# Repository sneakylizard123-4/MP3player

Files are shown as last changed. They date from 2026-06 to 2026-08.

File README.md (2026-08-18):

# MP3 Player

A pocket-sized music player I designed and built from scratch. It plays audio off a microSD card, tunes into FM radio, and can record through a MEMS microphone — all on one 50×70mm PCB with an OLED screen, RGB LEDs, and seventeen physical buttons.

It's built around an STM32H743 running at 480MHz, and the audio comes out through a CS43131 DAC. The whole thing was designed in KiCad 10 and the firmware is C++ written with PlatformIO on ST's HAL.

## Why I built this

I wanted a music player that was actually *mine*. Phones sound great and all, but you can't change anything about them — the hardware is sealed up, there's no satisfying button to press, and the software only does what the manufacturer lets it do. I wanted real buttons, a screen, lights that react to the music, and firmware I could rewrite from scratch whenever I felt like it.

It also turned out to be the perfect excuse to practice the stuff I actually enjoy: PCB design, embedded firmware, and getting hardware interfaces to talk to each other.

I went with the STM32H743 because it has the RAM to buffer audio properly, enough peripherals for everything I wanted to add, and 480MHz of headroom so I never have to worry about it being slow.

## Pictures

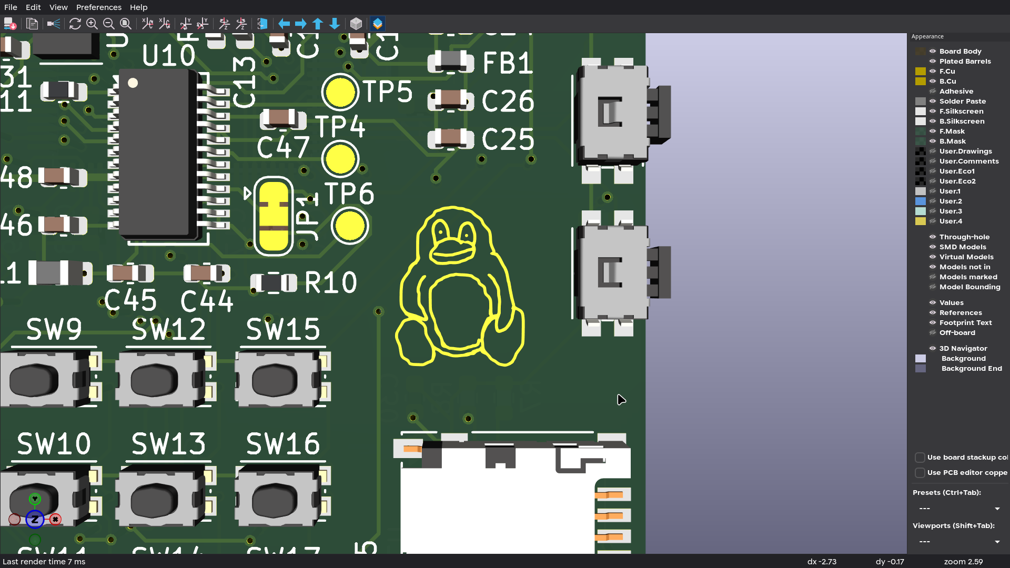
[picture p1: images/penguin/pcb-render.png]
3D render


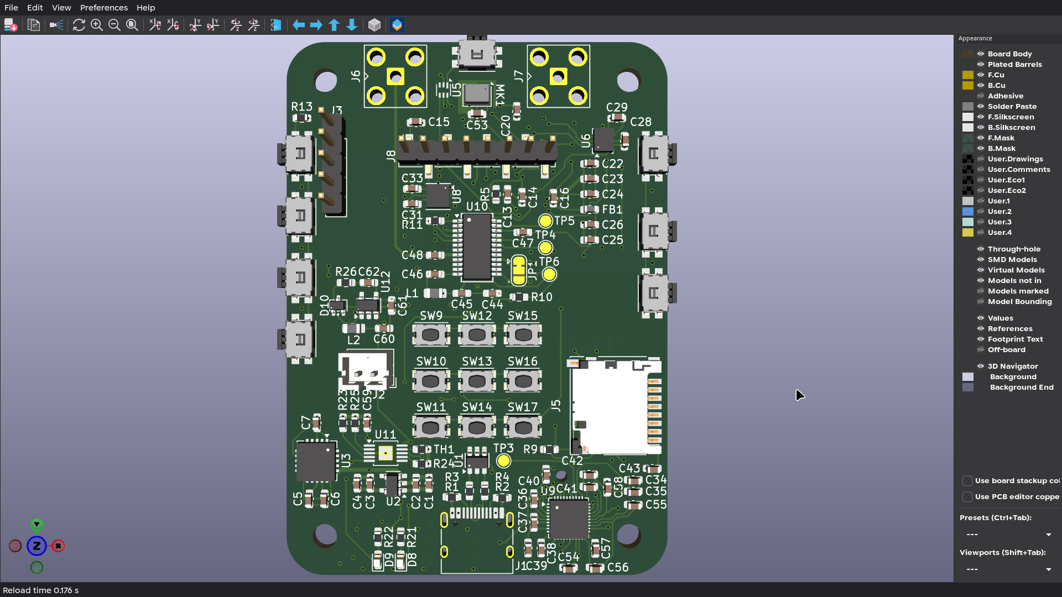
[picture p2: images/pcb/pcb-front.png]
PCB front
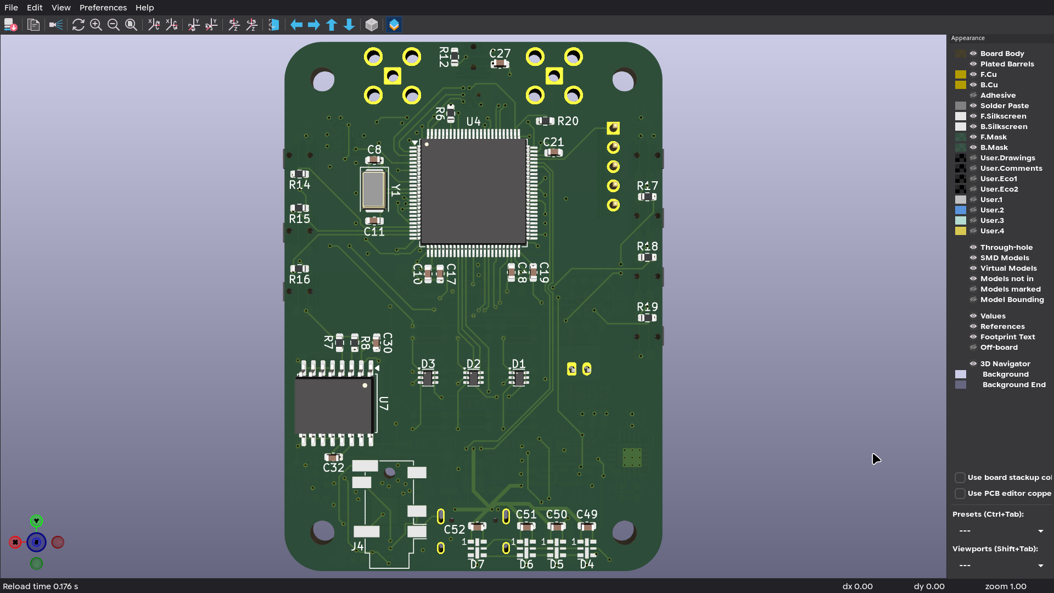
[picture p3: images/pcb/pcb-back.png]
PCB back
 | 

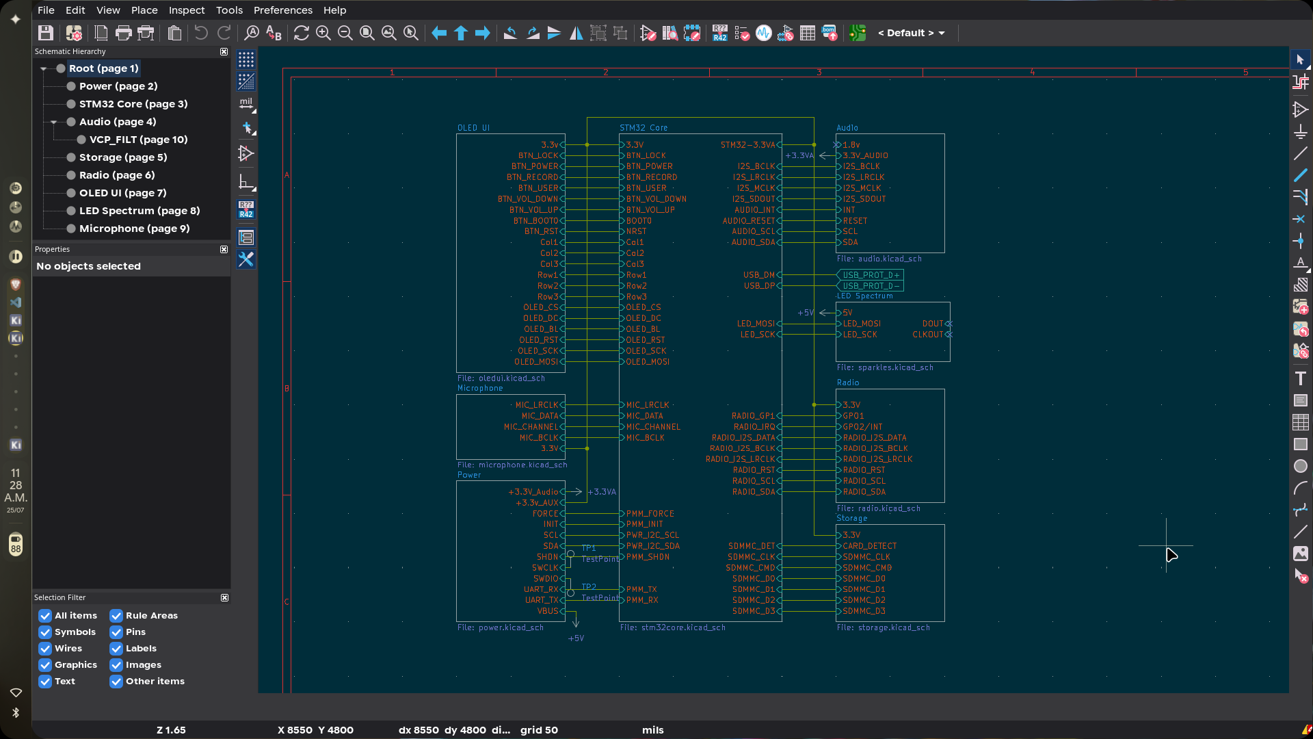
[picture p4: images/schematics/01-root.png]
Root schematic


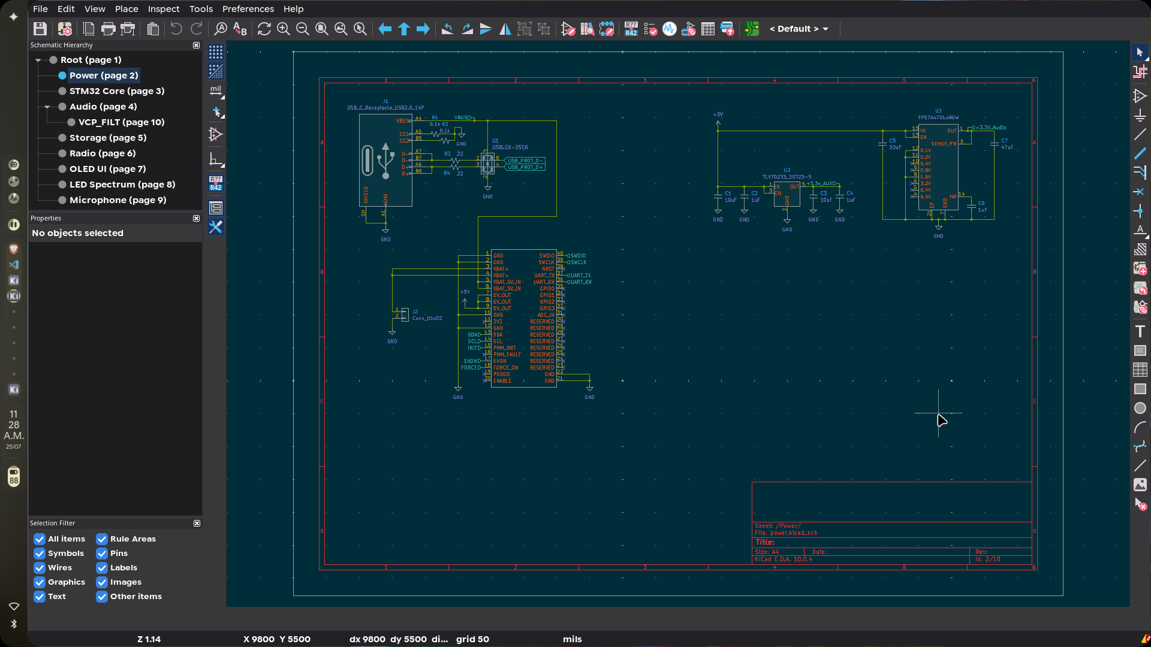
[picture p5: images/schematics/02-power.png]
Power schematic


## Features

**Audio**

* CS43131 high-res headphone DAC with a built-in amp
* Dedicated low-noise power rail just for the audio stuff
* 3.5mm headphone output
* Si4735 AM/FM radio receiver
* ICS-43434 I2S microphone for recording

**Storage & controls**

* microSD card over 4-bit SDMMC
* OLED display
* 17 buttons: a 3×3 matrix for navigation plus direct controls
* APA102 RGB LEDs

**Sensors**

* LSM6DSL 6-axis IMU
* BME680 temperature / humidity / pressure / gas sensor
* ISL29035 ambient light sensor
* DS3231M real-time clock

**Power**

* USB-C charging via a BQ24090DGQ Li-ion charger
* TPS613222ADBV boost converter for the 5V rail
* Separate digital and low-noise analog rails

## What the sensors actually do

None of these are needed to play music, but they're what turn this from "a box that plays audio" into something that notices the world around it:

* **LSM6DSL IMU** — motion and orientation. You could shake it to skip a track, flip it to mute, rotate the UI, or drive the LEDs off the beat.
* **BME680** — temperature, humidity, pressure, and VOC levels. Nice for showing environmental data on the OLED, and it can track air quality over time.
* **ISL29035** — how bright it is outside. Auto-adjusts the OLED brightness so it stays readable in daylight and saves battery at night.
* **DS3231M RTC** — keeps accurate time even when the player is off, for a clock on the display, recording timestamps, and maybe alarms later.

# Hardware

## Power

A single Li-ion cell powers everything, with separate rails for the digital side, the LEDs, and the analog audio. The charger (BQ24090DGQ) handles USB input, battery management, and has an NTC thermistor on the pack for temperature monitoring plus charge status LEDs. The boost converter (TPS613222ADBV) steps the battery up to 5V for the LEDs and peripherals, a TLV70233 LDO makes the 3.3V digital rail, and a TPS7A4701 low-noise LDO feeds the audio.

Power flow:

```
USB-C
  |
  +-- USBLC6 ESD protection
  |
  +-- BQ24090DGQ Li-ion charger
          |
          +-- Li-ion battery
                  |
                  +-- TPS613222ADBV boost converter
                  |       |
                  |       +-- 5V rail (LEDs and peripherals)
                  |
                  +-- TLV70233 LDO
                  |       |
                  |       +-- 3.3V digital rail
                  |
                  +-- TPS7A4701 low-noise LDO
                          |
                          +-- audio rail
```

The digital and audio rails are deliberately kept apart so switching noise from the boost converter doesn't end up in your headphones. The DAC gets its own clean regulator for the same reason.

## Schematic

The design is split across hierarchical KiCad sheets:

| Sheet | File | Description | Main Components |
| --- | --- | --- | --- |
| Root | MP3player.kicad_sch | Connections and system overview | Power symbols, connectors, mounting holes |
| STM32 Core | stm32core.kicad_sch | MCU and sensors | STM32H743, LSM6DSL, BME680, ISL29035, DS3231M |
| Power | power.kicad_sch | Charging and regulation | BQ24090DGQ, TPS613222ADBV, TPS7A4701, TLV70233, USBLC6 |
| Audio | audio.kicad_sch | Headphone audio path | CS43131-CNZR |
| Storage | storage.kicad_sch | Removable storage | MicroSD socket |
| OLED UI | oledui.kicad_sch | Display and buttons | OLED, button matrix, GPIO controls |
| Radio | radio.kicad_sch | AM/FM receiver | Si4735-D60-GU |
| Microphone | microphone.kicad_sch  | Audio input | ICS-43434 MEMS microphone |
| LED Spectrum | ledspectrum.kicad_sch | Visual audio display | APA102-2020 LEDs |

## PCB

Six layers, 1.6mm thick, about 50×70mm. Internal power planes keep the distribution clean, and I paid attention to keeping the analog audio away from the digital and switching sections. The DAC sits right next to the headphone jack so the analog traces stay short, and the high-current paths around the charger and boost converter are kept tight with proper return paths.

# Assembly

Designed for standard SMT assembly. Here's how it goes together:

1. Apply solder paste with the stencil.
2. Place the small stuff — 0603 resistors and caps, ferrite beads, crystals.
3. Place the big ICs: STM32H743 (LQFP-100), CS43131, Si4735, power management, APA102 LEDs, sensors.
4. Reflow.
5. Check the fine-pitch parts for solder bridges.
6. Install connectors: USB-C, headphone jack, microSD socket, SMA antenna connectors, battery connector, debug headers.
7. Install the user-facing stuff: 17 tactile switches and the OLED connector.
8. Electrical checks — continuity, shorts, and verifying the power rails.
9. Flash the initial firmware over SWD.

## Firmware

The firmware is in `firmware/`, built with PlatformIO on the STM32 HAL. Right now it sets up the hardware: 480MHz clock from the 8MHz crystal via PLL, all the GPIO, the I2C/SPI/UART buses, the SD card interface, and the control pins. The fun part — actual playback, the UI, radio control, recording, and the LED effects — is still being written.

### Build and flash

You'll need PlatformIO (CLI or the VS Code extension) and an ST-Link, CMSIS-DAP, or J-Link debugger.

```bash
cd firmware
pio run
```

To flash over SWD:

```bash
pio run -t upload
```

# Bill of Materials

| Ref | Part | Qty | Package | Description |
| --- | --- | --- | --- | --- |
| U4 | STM32H743VIT6 | 1 | LQFP-100  | Main microcontroller |
| U9 | CS43131-CNZR | 1 | QFN-40 | Audio DAC |
| U10 | Si4735-D60-GU | 1 | SSOP-24 | FM radio receiver |
| MK1 | ICS-43434 | 1 | LGA | I2S MEMS microphone |
| U6 | LSM6DSL | 1 | LGA-14 | 6-axis IMU |
| U8 | BME680 | 1 | LGA-8 | Environmental sensor |
| U5 | ISL29035 | 1 | DFN-6 | Ambient light sensor |
| U7 | DS3231M | 1 | SOIC-16W  | Real-time clock |
| U11 | BQ24090DGQ | 1 | HVSSOP-10 | Li-ion charger |
| U12 | TPS613222ADBV | 1 | SOT-23-5  | Boost converter |
| U3 | TPS7A4701xRGW | 1 | VQFN-20 | Low-noise audio regulator |
| U2 | TLV70233 | 1 | SOT-23-5  | 3.3V digital regulator |
| U1 | USBLC6-2SC6 | 1 | SOT-23-6  | USB ESD protection |
| D4-D7 | APA102-2020 | 4 | 2×2mm | RGB LEDs |
| D1-D3 | ACDSV6-4448TI-G | 3 | SOT-363 | Button ESD protection |
| D10 | BAT54W | 1 | SOT-323 | Schottky diode |
| D8-D9 | 0603 LEDs | 2 | 0603 | Status LEDs |
| J1 | HRO TYPE-C-31-M-12 | 1 | USB-C | Charging and USB |
| J4 | PJ31060-I | 1 | — | 3.5mm headphone jack |
| J5 | Hirose DM3D-SF | 1 | — | MicroSD socket |
| J6-J7 | Amphenol 901-143 | 2 | SMA | Antenna connectors |
| J2 | JST PH B2B-PH-K | 1 | 2.0mm | Battery connector |
| J3 | SWD header | 1 | 2.54mm | Debug connector |
| J8 | OLED header | 1 | 2.54mm | Display connector |
| L1 | 450µH | 1 | 0805 | Radio antenna matching |
| L2 | 2.2µH | 1 | 0805 | Boost converter inductor |
| Y1 | 8MHz TXC AA08000002  | 1 | 5032 | MCU crystal |
| SW1-SW17 | Tactile switches | 17  | — | User controls |
| TH1 | 10k NTC | 1 | 0603 | Battery temperature monitoring |
| FB1 | 600Ω @100MHz ferrite | 1 | 0603 | Noise filtering |

`BOM.csv` has the full BOM with supplier part numbers, links, and pricing.

# Fabrication

Gerbers are in kicad/production/MP3player.zip

Boards and stencils are made through JLCPCB.

PCB specs:

| Specification  | Value |
| --- | --- |
| Layers | 6 |
| Dimensions | 50×70mm |
| Thickness | 1.6mm |
| Material | FR-4 TG155 |
| Surface finish | ENIG |
| Outer copper | 1oz |
| Inner copper | 0.5oz |
| PCB color | Purple |
| Silkscreen | White |

Stencil specs:

| Specification | Value |
| --- | --- |
| Quantity | 2 |
| Sides | Top and bottom |
| Manufacturing process | Laser-cut stainless steel |
| Finish | Electropolished |
| Coating | Nano-coating |

# Known Issues

* Audio performance hasn't been measured with the final firmware yet.
* Battery runtime still needs to be measured.
* RF performance and antenna tuning need real testing.
* Thermal behavior under load hasn't been validated.
* The enclosure design isn't done.

The firmware currently only does hardware init. Remaining features:

* [ ] Audio playback pipeline
* [ ] SD card filesystem support
* [ ] Audio decoding
* [ ] OLED user interface
* [ ] Button handling and debounce
* [ ] Radio control
* [ ] Recording
* [ ] Sensor drivers
* [ ] LED spectrum visualization
* [ ] Battery monitoring

# Credits

* Board, schematics, and firmware designed and written from scratch by me.
* STM32 HAL by STMicroelectronics.
* PlatformIO for firmware builds.
* KiCad libraries for standard symbols and footprints.

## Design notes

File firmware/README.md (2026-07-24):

# MP3 Player Firmware

PlatformIO firmware for an STM32H743VIT6-based portable MP3 player.

## Hardware

| Component | Part | Interface |
|---|---|---|
| MCU | STM32H743VIT6 (Cortex-M7, 480MHz, 2MB Flash, 1MB RAM) | — |
| Audio DAC | CS43131-CNZR | I2S + I2C |
| FM Radio | Si4735-D60-GU | I2S + I2C |
| Microphone | ICS-43434 | I2S |
| IMU | LSM6DSL | SPI |
| Gas Sensor | BME680 | SPI |
| Light Sensor | ISL29035 | I2C |
| RTC | DS3231M | I2C |
| OLED Display | SPI (via Conn_01x08) | SPI |
| SD Card | Micro SD (4-bit SDMMC) | SDMMC |
| LEDs | 70x APA102-2020 | SPI |
| Power Mgmt | PMM (STM32-based module) | UART + I2C |
| USB | USB 2.0 (USB-C) | USB FS |

## Build

```bash
cd firmware
pio run
```

Output: `.pio/build/stm32h743/firmware.bin`

## Flash

```bash
pio run -t upload
```

Requires ST-Link, CMSIS-DAP, or J-Link debugger connected via SWD.

## Project Structure

```
firmware/
├── platformio.ini                  # Build config
├── include/
│   ├── stm32h7xx_hal_conf.h       # HAL module selection
│   ├── pins.h                      # All GPIO assignments from schematic
│   └── config.h                    # Clock, bus speed, and system constants
└── src/
    ├── main.cpp                    # Clock config, peripheral init, main loop
    └── msp.cpp                     # HAL MSP callbacks (pin muxing)
```

## Pin Mapping

### Buttons (direct, active low)
| Pin | Signal |
|-----|---|
| PA0 | BTN_POWER |
| PA1 | BTN_VOL_UP |
| PA2 | BTN_VOL_DOWN |
| PA3 | BTN_LOCK |
| PA4 | BTN_RECORD |
| PC1 | BTN_USER |
| PC0 | BTN_BOOT0 |

### Button Matrix (3x3)
| Pin | Signal |
|-----|---|
| PB0 | COL1 |
| PB1 | COL2 |
| PB2 | COL3 |
| PB3 | ROW1 |
| PB4 | ROW2 |
| PC0 | ROW3 |

### OLED Display (SPI4)
| Pin | Signal |
|-----|---|
| PA5 | OLED_SCK |
| PA7 | OLED_MOSI |
| PB6 | OLED_CS |
| PB7 | OLED_DC |
| PA6 | OLED_RST |
| PB5 | OLED_BL |

### Audio DAC (CS43131 — SAI1 + I2C4)
| Pin | Signal |
|-----|---|
| PE1 | I2S_MCLK |
| PE11 | I2S_LRCLK |
| PE12 | I2S_BCLK |
| PE14 | I2S_SDOUT |
| PE0 | AUDIO_SDA |
| PE1 | AUDIO_SCL |
| PD3 | AUDIO_INT |
| PD4 | AUDIO_RESET |

### FM Radio (Si4735 — SAI2 + I2C)
| Pin | Signal |
|-----|---|
| PB10 | RADIO_I2S_BCLK |
| PB12 | RADIO_I2S_LRCLK |
| PB15 | RADIO_I2S_DATA |
| PD12 | RADIO_SCL |
| PD13 | RADIO_SDA |
| PD14 | RADIO_RST |
| PD11 | RADIO_IRQ |

### Microphone (ICS-43434 — I2S)
| Pin | Signal |
|-----|---|
| PE2 | MIC_DATA |
| PE3 | MIC_LRCLK |
| PE4 | MIC_BCLK |
| PA15 | MIC_CHANNEL |

### Sensors (SPI1 + I2C1)
| Pin | Signal |
|-----|---|
| PE13 | SENSORS_SPI_SCK |
| PE5 | SENSORS_SPI_MISO |
| PE6 | SENSORS_SPI_MOSI |
| PE8 | IMU_CS |
| PE10 | GAS_CS |
| PE9 | IMU_INT1 |
| PC2 | IMU_INT2 |
| PC3 | LIGHT_INT |
| PD0 | SENSORS_I2C_SCL |
| PD1 | SENSORS_I2C_SDA |

### SD Card (SDMMC1)
| Pin | Signal |
|-----|---|
| PC12 | SDMMC_CLK |
| PC13 | SDMMC_CMD |
| PC8 | SDMMC_D0 |
| PC9 | SDMMC_D1 |
| PC10 | SDMMC_D2 |
| PC11 | SDMMC_D3 |
| PC7 | SDMMC_DET |

### LED Strip (APA102)
| Pin | Signal |
|-----|---|
| PB11 | LED_SCK |
| PB13 | LED_MOSI |

### Power Management (PMM)
| Pin | Signal |
|-----|---|
| PD8 | PMM_TX (USART3) |
| PD9 | PMM_RX (USART3) |
| PD7 | PMM_FORCE |
| PD10 | PMM_SHDN |
| PD15 | PMM_INIT |
| PB8 | PWR_I2C_SCL |
| PB9 | PWR_I2C_SDA |

### USB
| Pin | Signal |
|-----|---|
| PA11 | USB_DM |
| PA12 | USB_DP |

### Clock
| Pin | Signal |
|-----|---|
| PH0 | HSE_IN (8MHz crystal) |
| PH1 | HSE_OUT |
| PC14 | LSE_IN (32.768kHz crystal) |
| PC15 | LSE_OUT |

### Debug (SWD)
| Pin | Signal |
|-----|---|
| PA13 | SWDIO |
| PA14 | SWCLK |

## Clock Tree

- **SYSCLK**: 480MHz (8MHz HSE / 4 * 240)
- **AHB**: 240MHz (/2)
- **APB1/APB2**: 120MHz (/2)
- **SDMMC**: 48MHz (from PLL1Q)
- **PLL2**: Audio clock source (SAI1, SAI2)
- **USB**: 48MHz (from PLL1Q)

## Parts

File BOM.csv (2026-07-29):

Refs | Value | Footprint | Qty | LCSC# | MPN | Manufacturer | Unit Price($) | Product Link
C1 | 10uF | Capacitor_SMD:C_0603_1608Metric | 1 | C19702 | CL10A106KP8NNNC | Samsung Electro-Mechanics | 0.0390 | https://www.lcsc.com/product-detail/C19702.html
C2 | 1uF | Capacitor_SMD:C_0603_1608Metric | 1 | C29936 | CL10B105KA8NNNC | Samsung Electro-Mechanics | 0.0229 | https://www.lcsc.com/product-detail/C29936.html
C3 | 10uF | Capacitor_SMD:C_0603_1608Metric | 1 | C19702 | CL10A106KP8NNNC | Samsung Electro-Mechanics | 0.0390 | https://www.lcsc.com/product-detail/C19702.html
C4 | 1uF | Capacitor_SMD:C_0603_1608Metric | 1 | C29936 | CL10B105KA8NNNC | Samsung Electro-Mechanics | 0.0229 | https://www.lcsc.com/product-detail/C29936.html
C5 | 10uF | Capacitor_SMD:C_0603_1608Metric | 1 | C19702 | CL10A106KP8NNNC | Samsung Electro-Mechanics | 0.0390 | https://www.lcsc.com/product-detail/C19702.html
C6 | 1uF | Capacitor_SMD:C_0603_1608Metric | 1 | C29936 | CL10B105KA8NNNC | Samsung Electro-Mechanics | 0.0229 | https://www.lcsc.com/product-detail/C29936.html
C7 | 47uF | Capacitor_SMD:C_0603_1608Metric | 1 | C140782 | GRM188R60J476ME15D | muRata | 0.2397 | https://www.lcsc.com/product-detail/C140782.html
C8 | 12pF | Capacitor_SMD:C_0603_1608Metric | 1 | C107034 | CC0603JRNPO9BN120 | YAGEO | 0.0090 | https://www.lcsc.com/product-detail/C107034.html
C10 | 0.1uF | Capacitor_SMD:C_0603_1608Metric | 1 | C1591 | CL10B104KB8NNNC | Samsung Electro-Mechanics | 0.0160 | https://www.lcsc.com/product-detail/C1591.html
C11 | 12pF | Capacitor_SMD:C_0603_1608Metric | 1 | C107034 | CC0603JRNPO9BN120 | YAGEO | 0.0090 | https://www.lcsc.com/product-detail/C107034.html
C13 | 100nF | Capacitor_SMD:C_0603_1608Metric | 1 | C1591 | CL10B104KB8NNNC | Samsung Electro-Mechanics | 0.0160 | https://www.lcsc.com/product-detail/C1591.html
C14 | 0.1uF | Capacitor_SMD:C_0603_1608Metric | 1 | C1591 | CL10B104KB8NNNC | Samsung Electro-Mechanics | 0.0160 | https://www.lcsc.com/product-detail/C1591.html
C15 | 0.1uF | Capacitor_SMD:C_0603_1608Metric | 1 | C1591 | CL10B104KB8NNNC | Samsung Electro-Mechanics | 0.0160 | https://www.lcsc.com/product-detail/C1591.html
C16 | 100nF | Capacitor_SMD:C_0603_1608Metric | 1 | C1591 | CL10B104KB8NNNC | Samsung Electro-Mechanics | 0.0160 | https://www.lcsc.com/product-detail/C1591.html
C17 | 0.1uF | Capacitor_SMD:C_0603_1608Metric | 1 | C1591 | CL10B104KB8NNNC | Samsung Electro-Mechanics | 0.0160 | https://www.lcsc.com/product-detail/C1591.html
C18 | 2.2uF | Capacitor_SMD:C_0603_1608Metric | 1 | C23630 | CL10A225KO8NNNC | Samsung Electro-Mechanics | 0.0289 | https://www.lcsc.com/product-detail/C23630.html
C19 | 100nF | Capacitor_SMD:C_0603_1608Metric | 1 | C1591 | CL10B104KB8NNNC | Samsung Electro-Mechanics | 0.0160 | https://www.lcsc.com/product-detail/C1591.html
C20 | 0.1uF | Capacitor_SMD:C_0603_1608Metric | 1 | C1591 | CL10B104KB8NNNC | Samsung Electro-Mechanics | 0.0160 | https://www.lcsc.com/product-detail/C1591.html
C21 | 2.2uF | Capacitor_SMD:C_0603_1608Metric | 1 | C23630 | CL10A225KO8NNNC | Samsung Electro-Mechanics | 0.0289 | https://www.lcsc.com/product-detail/C23630.html
C22 | 10nF | Capacitor_SMD:C_0603_1608Metric | 1 | C100042 | CC0603KRX7R9BB103 | YAGEO | 0.0160 | https://www.lcsc.com/product-detail/C100042.html
C23 | 100nF | Capacitor_SMD:C_0603_1608Metric | 1 | C1591 | CL10B104KB8NNNC | Samsung Electro-Mechanics | 0.0160 | https://www.lcsc.com/product-detail/C1591.html
C24 | 1uF | Capacitor_SMD:C_0603_1608Metric | 1 | C29936 | CL10B105KA8NNNC | Samsung Electro-Mechanics | 0.0229 | https://www.lcsc.com/product-detail/C29936.html
C25 | 1uF | Capacitor_SMD:C_0603_1608Metric | 1 | C29936 | CL10B105KA8NNNC | Samsung Electro-Mechanics | 0.0229 | https://www.lcsc.com/product-detail/C29936.html
C26 | 100nF | Capacitor_SMD:C_0603_1608Metric | 1 | C1591 | CL10B104KB8NNNC | Samsung Electro-Mechanics | 0.0160 | https://www.lcsc.com/product-detail/C1591.html
C27 | 100nF | Capacitor_SMD:C_0603_1608Metric | 1 | C1591 | CL10B104KB8NNNC | Samsung Electro-Mechanics | 0.0160 | https://www.lcsc.com/product-detail/C1591.html
C28 | 100nF | Capacitor_SMD:C_0603_1608Metric | 1 | C1591 | CL10B104KB8NNNC | Samsung Electro-Mechanics | 0.0160 | https://www.lcsc.com/product-detail/C1591.html
C29 | 100nF | Capacitor_SMD:C_0603_1608Metric | 1 | C1591 | CL10B104KB8NNNC | Samsung Electro-Mechanics | 0.0160 | https://www.lcsc.com/product-detail/C1591.html
C30 | 100nF | Capacitor_SMD:C_0603_1608Metric | 1 | C1591 | CL10B104KB8NNNC | Samsung Electro-Mechanics | 0.0160 | https://www.lcsc.com/product-detail/C1591.html
C31 | 100nF | Capacitor_SMD:C_0603_1608Metric | 1 | C1591 | CL10B104KB8NNNC | Samsung Electro-Mechanics | 0.0160 | https://www.lcsc.com/product-detail/C1591.html
C32 | 100nF | Capacitor_SMD:C_0603_1608Metric | 1 | C1591 | CL10B104KB8NNNC | Samsung Electro-Mechanics | 0.0160 | https://www.lcsc.com/product-detail/C1591.html
C33 | 100nF | Capacitor_SMD:C_0603_1608Metric | 1 | C1591 | CL10B104KB8NNNC | Samsung Electro-Mechanics | 0.0160 | https://www.lcsc.com/product-detail/C1591.html
C34 | 100nF | Capacitor_SMD:C_0603_1608Metric | 1 | C1591 | CL10B104KB8NNNC | Samsung Electro-Mechanics | 0.0160 | https://www.lcsc.com/product-detail/C1591.html
C35 | 100nF | Capacitor_SMD:C_0603_1608Metric | 1 | C1591 | CL10B104KB8NNNC | Samsung Electro-Mechanics | 0.0160 | https://www.lcsc.com/product-detail/C1591.html
C36 | 15uF | Capacitor_SMD:C_0603_1608Metric | 1 | C445715 | C1608X5R0J156MT000E | TDK | 0.1322 | https://www.lcsc.com/product-detail/C445715.html
C37 | 15uF | Capacitor_SMD:C_0603_1608Metric | 1 | C445715 | C1608X5R0J156MT000E | TDK | 0.1322 | https://www.lcsc.com/product-detail/C445715.html
C38 | 2.2uF | Capacitor_SMD:C_0603_1608Metric | 1 | C23630 | CL10A225KO8NNNC | Samsung Electro-Mechanics | 0.0289 | https://www.lcsc.com/product-detail/C23630.html
C39 | 2.2uF | Capacitor_SMD:C_0603_1608Metric | 1 | C23630 | CL10A225KO8NNNC | Samsung Electro-Mechanics | 0.0289 | https://www.lcsc.com/product-detail/C23630.html
C40 | 2.2uF | Capacitor_SMD:C_0603_1608Metric | 1 | C23630 | CL10A225KO8NNNC | Samsung Electro-Mechanics | 0.0289 | https://www.lcsc.com/product-detail/C23630.html
C41 | 100nF | Capacitor_SMD:C_0603_1608Metric | 1 | C1591 | CL10B104KB8NNNC | Samsung Electro-Mechanics | 0.0160 | https://www.lcsc.com/product-detail/C1591.html
C42 | 4.7uF | Capacitor_SMD:C_0603_1608Metric | 1 | C19666 | CL10A475KO8NNNC | Samsung Electro-Mechanics | 0.0339 | https://www.lcsc.com/product-detail/C19666.html
C43 | 100nF | Capacitor_SMD:C_0603_1608Metric | 1 | C1591 | CL10B104KB8NNNC | Samsung Electro-Mechanics | 0.0160 | https://www.lcsc.com/product-detail/C1591.html
C44 | 0.1uF | Capacitor_SMD:C_0603_1608Metric | 1 | C1591 | CL10B104KB8NNNC | Samsung Electro-Mechanics | 0.0160 | https://www.lcsc.com/product-detail/C1591.html
C45 | 0.1uF | Capacitor_SMD:C_0603_1608Metric | 1 | C1591 | CL10B104KB8NNNC | Samsung Electro-Mechanics | 0.0160 | https://www.lcsc.com/product-detail/C1591.html
C46 | 1nF | Capacitor_SMD:C_0603_1608Metric | 1 | C100040 | CC0603KRX7R9BB102 | YAGEO | 0.0152 | https://www.lcsc.com/product-detail/C100040.html
C47 | 22nF | Capacitor_SMD:C_0603_1608Metric | 1 | C21122 | CL10B223KB8NNNC | Samsung Electro-Mechanics | 0.0151 | https://www.lcsc.com/product-detail/C21122.html
C48 | 1nF | Capacitor_SMD:C_0603_1608Metric | 1 | C100040 | CC0603KRX7R9BB102 | YAGEO | 0.0152 | https://www.lcsc.com/product-detail/C100040.html
C49 | 0.1uF | Capacitor_SMD:C_0603_1608Metric | 1 | C1591 | CL10B104KB8NNNC | Samsung Electro-Mechanics | 0.0160 | https://www.lcsc.com/product-detail/C1591.html
C50 | 0.1uF | Capacitor_SMD:C_0603_1608Metric | 1 | C1591 | CL10B104KB8NNNC | Samsung Electro-Mechanics | 0.0160 | https://www.lcsc.com/product-detail/C1591.html
C51 | 0.1uF | Capacitor_SMD:C_0603_1608Metric | 1 | C1591 | CL10B104KB8NNNC | Samsung Electro-Mechanics | 0.0160 | https://www.lcsc.com/product-detail/C1591.html
C52 | 0.1uF | Capacitor_SMD:C_0603_1608Metric | 1 | C1591 | CL10B104KB8NNNC | Samsung Electro-Mechanics | 0.0160 | https://www.lcsc.com/product-detail/C1591.html
C53 | 100nF | Capacitor_SMD:C_0603_1608Metric | 1 | C1591 | CL10B104KB8NNNC | Samsung Electro-Mechanics | 0.0160 | https://www.lcsc.com/product-detail/C1591.html
C54 | 2.2uF | Capacitor_SMD:C_0603_1608Metric | 1 | C23630 | CL10A225KO8NNNC | Samsung Electro-Mechanics | 0.0289 | https://www.lcsc.com/product-detail/C23630.html
C55 | 2.2uF | Capacitor_SMD:C_0603_1608Metric | 1 | C23630 | CL10A225KO8NNNC | Samsung Electro-Mechanics | 0.0289 | https://www.lcsc.com/product-detail/C23630.html
C56 | 2.2uF | Capacitor_SMD:C_0603_1608Metric | 1 | C23630 | CL10A225KO8NNNC | Samsung Electro-Mechanics | 0.0289 | https://www.lcsc.com/product-detail/C23630.html
C57 | 2.2uF | Capacitor_SMD:C_0603_1608Metric | 1 | C23630 | CL10A225KO8NNNC | Samsung Electro-Mechanics | 0.0289 | https://www.lcsc.com/product-detail/C23630.html
C58 | 2.2uF | Capacitor_SMD:C_0603_1608Metric | 1 | C23630 | CL10A225KO8NNNC | Samsung Electro-Mechanics | 0.0289 | https://www.lcsc.com/product-detail/C23630.html
C59 | 1uF | Capacitor_SMD:C_0603_1608Metric | 1 | C29936 | CL10B105KA8NNNC | Samsung Electro-Mechanics | 0.0229 | https://www.lcsc.com/product-detail/C29936.html
C60 | 4.7uF | Capacitor_SMD:C_0603_1608Metric | 1 | C19666 | CL10A475KO8NNNC | Samsung Electro-Mechanics | 0.0339 | https://www.lcsc.com/product-detail/C19666.html
C61 | 22uF | Capacitor_SMD:C_0603_1608Metric | 1 | C2762594 | CL10A226MO7JZNC | Samsung Electro-Mechanics | 0.1293 | https://www.lcsc.com/product-detail/C2762594.html
C62 | 120pF | Capacitor_SMD:C_0603_1608Metric | 1 | C107035 | CC0603JRNPO9BN121 | YAGEO | 0.0077 | https://www.lcsc.com/product-detail/C107035.html
D1 | ACDSV6-4448TI-G | Package_TO_SOT_SMD:SOT-363_SC-70-6 | 1 | C17669451 | ACDSV6-4448TI-G | Comchip | 0.1650 | https://www.lcsc.com/product-detail/C17669451.html
D2 | ACDSV6-4448TI-G | Package_TO_SOT_SMD:SOT-363_SC-70-6 | 1 | C17669451 | ACDSV6-4448TI-G | Comchip | 0.1650 | https://www.lcsc.com/product-detail/C17669451.html
D3 | ACDSV6-4448TI-G | Package_TO_SOT_SMD:SOT-363_SC-70-6 | 1 | C17669451 | ACDSV6-4448TI-G | Comchip | 0.1650 | https://www.lcsc.com/product-detail/C17669451.html
D4 | APA102-2020 | LED_SMD:LED-APA102-2020 | 1 | C22439302 | APA102-2020 SuperLED | Led-Color | 0.0583 | https://www.lcsc.com/product-detail/C22439302.html
D5 | APA102-2020 | LED_SMD:LED-APA102-2020 | 1 | C22439302 | APA102-2020 SuperLED | Led-Color | 0.0583 | https://www.lcsc.com/product-detail/C22439302.html
D6 | APA102-2020 | LED_SMD:LED-APA102-2020 | 1 | C22439302 | APA102-2020 SuperLED | Led-Color | 0.0583 | https://www.lcsc.com/product-detail/C22439302.html
D7 | APA102-2020 | LED_SMD:LED-APA102-2020 | 1 | C22439302 | APA102-2020 SuperLED | Led-Color | 0.0583 | https://www.lcsc.com/product-detail/C22439302.html
D8 | LED | LED_SMD:LED_0603_1608Metric | 1 | C19171390 | YLED0603R | YONGYUTAI | 0.0059 | https://www.lcsc.com/product-detail/C19171390.html
D9 | LED | LED_SMD:LED_0603_1608Metric | 1 | C19171394 | YLED0603B | YONGYUTAI | 0.0058 | https://www.lcsc.com/product-detail/C19171394.html
D10 | BAT54W | Package_TO_SOT_SMD:SOT-323_SC-70 | 1 | C41374260 | BAT54W | BORN | 0.0237 | https://www.lcsc.com/product-detail/C41374260.html
FB1 | 600R @ 100MHz | Inductor_SMD:L_0603_1608Metric | 1 | C19330 | BLM18AG601SN1D | muRata | 0.0149 | https://www.lcsc.com/product-detail/C19330.html
J1 | USB_C_Receptacle_USB2.0_14P | Connector_USB:USB_C_Receptacle_HRO_TYPE-C-31-M-12 | 1 | C165948 | TYPE-C-31-M-12 | Korean Hroparts Elec | 0.1709 | https://www.lcsc.com/product-detail/C165948.html
J2 | Conn_01x02 | Connector_JST:JST_PH_B2B-PH-K_1x02_P2.00mm_Vertical | 1 | C131337 | B2B-PH-K-S(LF)(SN) | JST | 0.0353 | https://www.lcsc.com/product-detail/C131337.html
J3 | Conn_01x05 | Connector_PinHeader_2.54mm:PinHeader_1x05_P2.54mm_Vertical | 1
J4 | AudioJack3_Ground_SwitchTR | Connector_Audio:Jack_3.5mm_PJ31060-I_Horizontal | 1 | C2939583 | PJ-31060 | HOOYA | 0.2397 | https://www.lcsc.com/product-detail/C2939583.html
J5 | Micro_SD_Card_Det2 | Connector_Card:microSD_HC_Hirose_DM3D-SF | 1 | C719027 | DM3D-SF | HRS | 1.1168 | https://www.lcsc.com/product-detail/C719027.html
J6 | SMA | Connector_Coaxial:SMA_Amphenol_901-143_Horizontal | 1
J7 | SMA | Connector_Coaxial:SMA_Amphenol_901-143_Horizontal | 1
J8 | Conn_01x08 | Connector_PinHeader_2.54mm:PinHeader_1x08_P2.54mm_Vertical_SMD_Pin1Right | 1
L1 | 450uH | Inductor_SMD:L_1206_3216Metric | 1 | C223408 | LB3218T471K | Taiyo Yuden | 0.0574 | https://www.lcsc.com/product-detail/C223408.html
L2 | 2.2uH | Inductor_SMD:L_0805_2012Metric | 1 | C383369 | MLP2012H2R2MT0S1 | TDK | 0.1099 | https://www.lcsc.com/product-detail/C383369.html
MK1 | ICS-43434 | Sensor_Audio:InvenSense_ICS-43434-6_3.5x2.65mm | 1 | C5656610 | ICS-43434 | TDK InvenSense | 4.6604 | https://www.lcsc.com/product-detail/C5656610.html
R1 | 5.1k | Resistor_SMD:R_0603_1608Metric | 1 | C2907044 | FRC0603F5101TS | FOJAN | 0.0027 | https://www.lcsc.com/product-detail/C2907044.html
R2 | 5.1k | Resistor_SMD:R_0603_1608Metric | 1 | C2907044 | FRC0603F5101TS | FOJAN | 0.0027 | https://www.lcsc.com/product-detail/C2907044.html
R3 | 22 | Resistor_SMD:R_0603_1608Metric | 1
R4 | 22 | Resistor_SMD:R_0603_1608Metric | 1
R5 | 10k | Resistor_SMD:R_0603_1608Metric | 1 | C844918 | CRCW060310K0FKEA | VISHAY | 0.0081 | https://www.lcsc.com/product-detail/C844918.html
R6 | 10k | Resistor_SMD:R_0603_1608Metric | 1 | C844918 | CRCW060310K0FKEA | VISHAY | 0.0081 | https://www.lcsc.com/product-detail/C844918.html
R7 | 10k | Resistor_SMD:R_0603_1608Metric | 1 | C844918 | CRCW060310K0FKEA | VISHAY | 0.0081 | https://www.lcsc.com/product-detail/C844918.html
R8 | 10k | Resistor_SMD:R_0603_1608Metric | 1 | C844918 | CRCW060310K0FKEA | VISHAY | 0.0081 | https://www.lcsc.com/product-detail/C844918.html
R9 | 10k | Resistor_SMD:R_0603_1608Metric | 1 | C844918 | CRCW060310K0FKEA | VISHAY | 0.0081 | https://www.lcsc.com/product-detail/C844918.html
R10 | 10k | Resistor_SMD:R_0603_1608Metric | 1 | C844918 | CRCW060310K0FKEA | VISHAY | 0.0081 | https://www.lcsc.com/product-detail/C844918.html
R11 | 600 | Resistor_SMD:R_0603_1608Metric | 1
R12 | 10k | Resistor_SMD:R_0603_1608Metric | 1 | C844918 | CRCW060310K0FKEA | VISHAY | 0.0081 | https://www.lcsc.com/product-detail/C844918.html
R13 | 10k | Resistor_SMD:R_0603_1608Metric | 1 | C844918 | CRCW060310K0FKEA | VISHAY | 0.0081 | https://www.lcsc.com/product-detail/C844918.html
R14 | 10k | Resistor_SMD:R_0603_1608Metric | 1 | C844918 | CRCW060310K0FKEA | VISHAY | 0.0081 | https://www.lcsc.com/product-detail/C844918.html
R15 | 10k | Resistor_SMD:R_0603_1608Metric | 1 | C844918 | CRCW060310K0FKEA | VISHAY | 0.0081 | https://www.lcsc.com/product-detail/C844918.html
R16 | 10k | Resistor_SMD:R_0603_1608Metric | 1 | C844918 | CRCW060310K0FKEA | VISHAY | 0.0081 | https://www.lcsc.com/product-detail/C844918.html
R17 | 10k | Resistor_SMD:R_0603_1608Metric | 1 | C844918 | CRCW060310K0FKEA | VISHAY | 0.0081 | https://www.lcsc.com/product-detail/C844918.html
R18 | 10k | Resistor_SMD:R_0603_1608Metric | 1 | C844918 | CRCW060310K0FKEA | VISHAY | 0.0081 | https://www.lcsc.com/product-detail/C844918.html
R19 | 10k | Resistor_SMD:R_0603_1608Metric | 1 | C844918 | CRCW060310K0FKEA | VISHAY | 0.0081 | https://www.lcsc.com/product-detail/C844918.html
R20 | 10k | Resistor_SMD:R_0603_1608Metric | 1 | C844918 | CRCW060310K0FKEA | VISHAY | 0.0081 | https://www.lcsc.com/product-detail/C844918.html
R21 | 1.5k | Resistor_SMD:R_0603_1608Metric | 1 | C2930050 | FRC0603F1501TS | FOJAN | 0.0026 | https://www.lcsc.com/product-detail/C2930050.html
R22 | 1.5k | Resistor_SMD:R_0603_1608Metric | 1 | C2930050 | FRC0603F1501TS | FOJAN | 0.0026 | https://www.lcsc.com/product-detail/C2930050.html
R23 | 1.1k | Resistor_SMD:R_0603_1608Metric | 1 | C2075552 | TNPW06031K10BEEA | VISHAY | 0.2991 | https://www.lcsc.com/product-detail/C2075552.html
R24 | 11k | Resistor_SMD:R_0603_1608Metric | 1 | C728581 | RT0603BRD0711KL | YAGEO | 0.0321 | https://www.lcsc.com/product-detail/C728581.html
R25 | 1.1k | Resistor_SMD:R_0603_1608Metric | 1 | C2075552 | TNPW06031K10BEEA | VISHAY | 0.2991 | https://www.lcsc.com/product-detail/C2075552.html
R26 | 5.11R | Resistor_SMD:R_0603_1608Metric | 1 | C170641 | WR06W5R11FTL | Walsin | 0.0015 | https://www.lcsc.com/product-detail/C170641.html
SW1 | SW_Push | Button_Switch_SMD:Panasonic_EVQPUM_EVQPUD | 1 | C388885 | EVQPUD02K | PANASONIC | 0.2299 | https://www.lcsc.com/product-detail/C388885.html
SW2 | SW_Push | Button_Switch_SMD:Panasonic_EVQPUM_EVQPUD | 1 | C388885 | EVQPUD02K | PANASONIC | 0.2299 | https://www.lcsc.com/product-detail/C388885.html
SW3 | SW_Push | Button_Switch_SMD:Panasonic_EVQPUM_EVQPUD | 1 | C388885 | EVQPUD02K | PANASONIC | 0.2299 | https://www.lcsc.com/product-detail/C388885.html
SW4 | SW_Push | Button_Switch_SMD:Panasonic_EVQPUM_EVQPUD | 1 | C388885 | EVQPUD02K | PANASONIC | 0.2299 | https://www.lcsc.com/product-detail/C388885.html
SW5 | SW_Push | Button_Switch_SMD:Panasonic_EVQPUM_EVQPUD | 1 | C388885 | EVQPUD02K | PANASONIC | 0.2299 | https://www.lcsc.com/product-detail/C388885.html
SW6 | SW_Push | Button_Switch_SMD:Panasonic_EVQPUM_EVQPUD | 1 | C388885 | EVQPUD02K | PANASONIC | 0.2299 | https://www.lcsc.com/product-detail/C388885.html
SW7 | SW_Push | Button_Switch_SMD:Panasonic_EVQPUM_EVQPUD | 1 | C388885 | EVQPUD02K | PANASONIC | 0.2299 | https://www.lcsc.com/product-detail/C388885.html
SW8 | SW_Push | Button_Switch_SMD:Panasonic_EVQPUM_EVQPUD | 1 | C388885 | EVQPUD02K | PANASONIC | 0.2299 | https://www.lcsc.com/product-detail/C388885.html
SW9 | SW_Push | Button_Switch_SMD:SW_Push_1P1T_NO_CK_KMR2 | 1 | C388885 | EVQPUD02K | PANASONIC | 0.2299 | https://www.lcsc.com/product-detail/C388885.html
SW10 | SW_Push | Button_Switch_SMD:SW_Push_1P1T_NO_CK_KMR2 | 1 | C388885 | EVQPUD02K | PANASONIC | 0.2299 | https://www.lcsc.com/product-detail/C388885.html
SW11 | SW_Push | Button_Switch_SMD:SW_Push_1P1T_NO_CK_KMR2 | 1 | C388885 | EVQPUD02K | PANASONIC | 0.2299 | https://www.lcsc.com/product-detail/C388885.html
SW12 | SW_Push | Button_Switch_SMD:SW_Push_1P1T_NO_CK_KMR2 | 1 | C388885 | EVQPUD02K | PANASONIC | 0.2299 | https://www.lcsc.com/product-detail/C388885.html
SW13 | SW_Push | Button_Switch_SMD:SW_Push_1P1T_NO_CK_KMR2 | 1 | C388885 | EVQPUD02K | PANASONIC | 0.2299 | https://www.lcsc.com/product-detail/C388885.html
SW14 | SW_Push | Button_Switch_SMD:SW_Push_1P1T_NO_CK_KMR2 | 1 | C388885 | EVQPUD02K | PANASONIC | 0.2299 | https://www.lcsc.com/product-detail/C388885.html
SW15 | SW_Push | Button_Switch_SMD:SW_Push_1P1T_NO_CK_KMR2 | 1 | C388885 | EVQPUD02K | PANASONIC | 0.2299 | https://www.lcsc.com/product-detail/C388885.html
SW16 | SW_Push | Button_Switch_SMD:SW_Push_1P1T_NO_CK_KMR2 | 1 | C388885 | EVQPUD02K | PANASONIC | 0.2299 | https://www.lcsc.com/product-detail/C388885.html
SW17 | SW_Push | Button_Switch_SMD:SW_Push_1P1T_NO_CK_KMR2 | 1 | C388885 | EVQPUD02K | PANASONIC | 0.2299 | https://www.lcsc.com/product-detail/C388885.html
TH1 | 10k | Resistor_SMD:R_0603_1608Metric | 1 | C844918 | CRCW060310K0FKEA | VISHAY | 0.0081 | https://www.lcsc.com/product-detail/C844918.html
U1 | USBLC6-2SC6 | Package_TO_SOT_SMD:SOT-23-6 | 1 | C7519 | USBLC6-2SC6 | ST | 0.1825 | https://www.lcsc.com/product-detail/C7519.html
U2 | TLV70233_SOT23-5 | Package_TO_SOT_SMD:SOT-23-5 | 1 | C51953287 | XTLV70233-XC | SiChange | 0.0519 | https://www.lcsc.com/product-detail/C51953287.html
U3 | TPS7A4701xRGW | Package_DFN_QFN:Texas_RGW0020A_VQFN-20-1EP_5x5mm_P0.65mm_EP3.15x3.15mm_ThermalVias | 1 | C68214 | TPS7A4701RGWT | TI | 5.4759 | https://www.lcsc.com/product-detail/C68214.html
U4 | STM32H743VIT6 | Package_QFP:LQFP-100_14x14mm_P0.5mm | 1 | C114409 | STM32H743VIT6 | ST | 15.0712 | https://www.lcsc.com/product-detail/C114409.html
U5 | ISL29035 | OptoDevice:Renesas_DFN-6_1.5x1.6mm_P0.5mm | 1 | C118347 | ISL29035IROZ-T7 | RENESAS | 0.8870 | https://www.lcsc.com/product-detail/C118347.html
U6 | LSM6DSL | Package_LGA:LGA-14_3x2.5mm_P0.5mm_LayoutBorder3x4y | 1 | C126672 | LSM6DSLTR | ST | 2.7347 | https://www.lcsc.com/product-detail/C126672.html
U7 | DS3231M | Package_SO:SOIC-16W_7.5x10.3mm_P1.27mm | 1 | C1520508 | DS3231M+ | MAXIM | 3.5756 | https://www.lcsc.com/product-detail/C1520508.html
U8 | BME680 | Package_LGA:Bosch_LGA-8_3x3mm_P0.8mm_ClockwisePinNumbering | 1 | C125972 | BME680 | Bosch | 10.8042 | https://www.lcsc.com/product-detail/C125972.html
U9 | CS43131-CNZR | Package_DFN_QFN:TQFN-40-1EP_5x5mm_P0.4mm_EP3.5x3.5mm | 1 | C965907 | CS43131-CNZR | Cirrus Logic | 3.6272 | https://www.lcsc.com/product-detail/C965907.html
U10 | Si4735-D60-GU | Package_SO:SSOP-24_3.9x8.7mm_P0.635mm | 1 | C1526089 | SI4735-D60-GU | SILICON LABS | 12.0922 | https://www.lcsc.com/product-detail/C1526089.html
U11 | BQ24090DGQ | Package_SO:HVSSOP-10-1EP_3x3mm_P0.5mm_EP1.83x1.89mm | 1 | C43306 | BQ24090DGQR | TI | 0.9495 | https://www.lcsc.com/product-detail/C43306.html
U12 | TPS613222ADBV | Package_TO_SOT_SMD:SOT-23-5 | 1 | C2071163 | TPS613222ADBVR | TI | 0.3711 | https://www.lcsc.com/product-detail/C2071163.html
Y1 | 8MHz TXC AA08000002 | Crystal:Crystal_SMD_5032-2Pin_5.0x3.2mm | 1 | C111903 | AA08000002 | TXC | 0.3377 | https://www.lcsc.com/product-detail/C111903.html
SW9-SW17 | SW_Push | Button_Switch_SMD:CK_KMR2 | 9 | C72443 | KMR221GLFS | C&K | 0.6515 | https://www.lcsc.com/product-detail/C72443.html
— | 0Ω | R_0603 | 1 | C4149532 | CR16000J | Meritek | 0.0026 | https://www.lcsc.com/product-detail/C4149532.html
— | 2.2kΩ NTC | 0603 | 2 | C17181196 | B57321V2222H060 | TDK | 0.0799 | https://www.lcsc.com/product-detail/C17181196.html
PARTS TOTAL |  |  |  |  |  |  |  | 75.82
PCB | 1 | 75x50mm | 1 |  |  | JLCPCB | 101
Stencil | 1 | 100x100mm | 1 |  |  | JLCPCB | 27
PCB shipping | 1 |  | 1 |  |  | GSDL | 12
PCB TOTAL |  |  |  |  |  |  |  | 140.00
ALL TOTAL |  |  |  |  |  |  |  | 215.82

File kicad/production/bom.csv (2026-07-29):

Designator | Footprint | Quantity | Value | LCSC Part #
C1, C3, C5 | 0603 | 3 | 10uF
C10, C14, C15, C17, C20, C44, C45, C49, C50, C51, C52 | 0603 | 11 | 0.1uF
C11, C8 | 0603 | 2 | 12pF
C13, C16, C19, C23, C26, C27, C28, C29, C30, C31, C32, C33, C34, C35, C41, C43, C53 | 0603 | 17 | 100nF
C18, C21, C38, C39, C40, C54, C55, C56, C57, C58 | 0603 | 10 | 2.2uF
C2, C24, C25, C4, C59, C6 | 0603 | 6 | 1uF
C22 | 0603 | 1 | 10nF
C36, C37 | 0603 | 2 | 15uF
C42, C60 | 0603 | 2 | 4.7uF
C46, C48 | 0603 | 2 | 1nF
C47 | 0603 | 1 | 22nF
C61 | 0603 | 1 | 22uF
C62 | 0603 | 1 | 120pF
C7 | 0603 | 1 | 47uF
D1, D2, D3 | SOT-363_SC-70-6 | 3 | ACDSV6-4448TI-G
D10 | SOT-323_SC-70 | 1 | BAT54W
D4, D5, D6, D7 | LED-APA102-2020 | 4 | APA102-2020
D8, D9 | 0603 | 2 | LED
FB1 | 0603 | 1 | 600R @ 100MHz
J1 | USB_C_Receptacle_HRO_TYPE-C-31-M-12 | 1 | USB_C_Receptacle_USB2.0_14P
J2 | JST_PH_B2B-PH-K_1x02_P2.00mm_Vertical | 1 | Conn_01x02
J3 | PinHeader_1x05_P2.54mm_Vertical | 1 | Conn_01x05
J4 | Jack_3.5mm_PJ31060-I_Horizontal | 1 | AudioJack3_Ground_SwitchTR
J5 | microSD_HC_Hirose_DM3D-SF | 1 | Micro_SD_Card_Det2
J6, J7 | SMA_Amphenol_901-143_Horizontal | 2 | SMA
J8 | PinHeader_1x08_P2.54mm_Vertical_SMD_Pin1Right | 1 | Conn_01x08
L1 | 1206 | 1 | 450uH
L2 | 0805 | 1 | 2.2uH
MK1 | InvenSense_ICS-43434-6_3.5x2.65mm | 1 | ICS-43434
R1, R2 | 0603 | 2 | 5.1k
R10, R12, R13, R14, R15, R16, R17, R18, R19, R20, R5, R6, R7, R8, R9, TH1 | 0603 | 16 | 10k
R11 | 0603 | 1 | 600
R21, R22 | 0603 | 2 | 1.5k
R23, R25 | 0603 | 2 | 1.1k
R24 | 0603 | 1 | 11k
R26 | 0603 | 1 | 5.11R
R3, R4 | 0603 | 2 | 22
SW1, SW2, SW3, SW4, SW5, SW6, SW7, SW8 | Panasonic_EVQPUM_EVQPUD | 8 | SW_Push
SW10, SW11, SW12, SW13, SW14, SW15, SW16, SW17, SW9 | SW_Push_1P1T_NO_CK_KMR2 | 9 | SW_Push
U1 | SOT-23-6 | 1 | USBLC6-2SC6
U10 | SSOP-24_3.9x8.7mm_P0.635mm | 1 | Si4735-D60-GU
U11 | HVSSOP-10-1EP_3x3mm_P0.5mm_EP1.83x1.89mm | 1 | BQ24090DGQ
U12 | SOT-23-5 | 1 | TPS613222ADBV
U2 | SOT-23-5 | 1 | TLV70233_SOT23-5
U3 | Texas_RGW0020A_VQFN-20-1EP_5x5mm_P0.65mm_EP3.15x3.15mm_ThermalVias | 1 | TPS7A4701xRGW
U4 | LQFP-100_14x14mm_P0.5mm | 1 | STM32H743VIT6
U5 | Renesas_DFN-6_1.5x1.6mm_P0.5mm | 1 | ISL29035
U6 | LGA-14_3x2.5mm_P0.5mm_LayoutBorder3x4y | 1 | LSM6DSL
U7 | SOIC-16W_7.5x10.3mm_P1.27mm | 1 | DS3231M
U8 | Bosch_LGA-8_3x3mm_P0.8mm_ClockwisePinNumbering | 1 | BME680
U9 | TQFN-40-1EP_5x5mm_P0.4mm_EP3.5x3.5mm | 1 | CS43131-CNZR | C965907
Y1 | Crystal_SMD_5032-2Pin_5.0x3.2mm | 1 | 8MHz TXC AA08000002

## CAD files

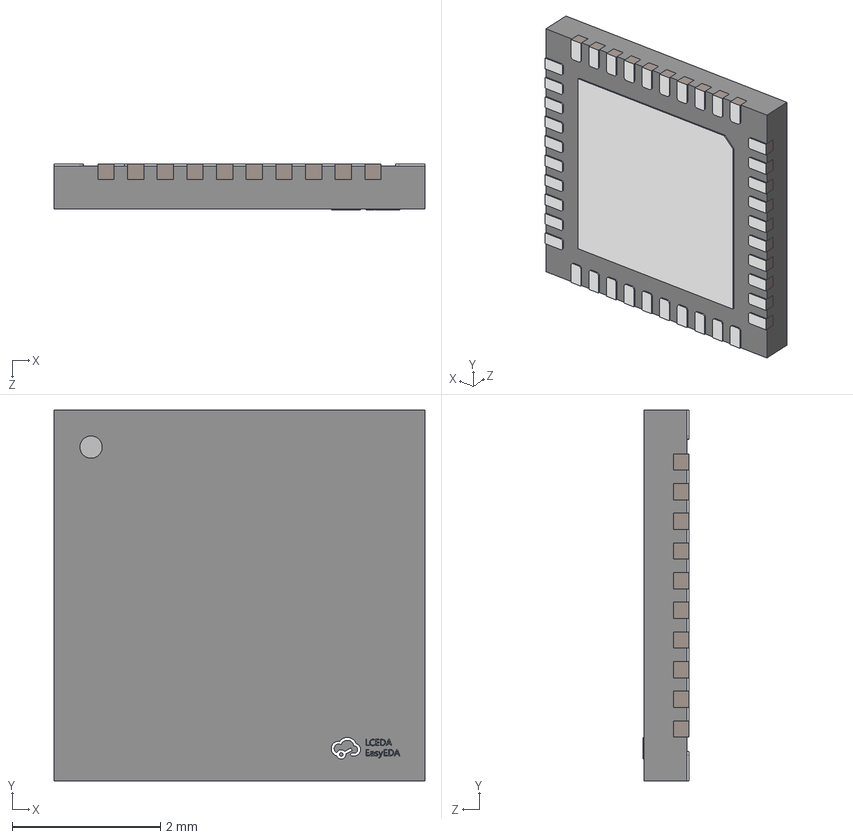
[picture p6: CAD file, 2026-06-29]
kicad/parts/CS4313-CNZR/3d/TQFN-40_L5.0-W5.0-P0.40-TL-EP3.5.step
5.00 x 5.00 x 0.615 mm

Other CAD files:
blender/MP3player.blend

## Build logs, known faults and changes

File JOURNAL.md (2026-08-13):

---
title: "MP3 Player"
author: sneak
description: "Portable MP3 player based on STM32H743 with CS43131 DAC, FM radio, OLED UI, and APA102 LEDs"
created_at: "2026-07-25T00:00:00Z"
---

# June 21: project start

started the mp3 player project. the plan was a portable player that can play files off an sd card, has fm radio, and looks cool with leds.

spent most of the time on part selection rather than actual designing. went back and forth on the mcu a lot - considered an esp32 but the thought of audio buffering while also driving a display and every peripheral on one chip made me nervous. settled on the stm32h743vit6 because it has 1mb of ram (enough to double buffer audio without sweating), a huge number of peripherals so every feature can have its own bus, and 480mhz so it's never the bottleneck. the downside is it's a pain to solder (lqfp-100) but i have a stencil so it's fine.

for the dac i picked the cs43131 because it has a built-in headphone amp so i don't need a separate one, and it sounds genuinely great. it also takes i2s directly which keeps the interface simple.

leds are apa102-2020 - only need clock and data lines which makes them easy to drive, they're tiny (2mm square) so i can pack a bunch in, and each one has its own pwm controller so no multiplexing nightmare.

root schematic

**Total time spent: 3 hours**

# June 22: schematic - mcu core

drew out the stm32h743 and all the core circuitry. this is the sheet everything else hangs off so i wanted to get it right.

started with the clocks. 8mhz hse crystal feeds the pll to run the chip at 480mhz, plus a 32.768khz lse crystal for the rtc so it keeps time when the device is off. put load caps on both - i remember reading that crystal load caps matter a lot for startup reliability, so i didn't skip them.

then the boring but important stuff: decoupling caps on every power pin. this chip has vdda, logic vdd, plus vcap pins for the internal voltage regulator, and i lost count of how many 100nf caps i placed. i grouped them as close to the pins as i could.

added the boot0 resistor so the chip boots from flash, an nrst pullup so reset is clean, and the swd header for programming. double checked the swd pin muxing because it's so easy to swap swclk and swdio.

the annoying part was mapping peripherals to pins. i started going through the alternate function table to figure out which pins can do i2c, spi, sai, sdmmc, etc. this chip has so many pins and nearly every one has like 4 alternate functions, so i kept going back and forth between pins. got a rough plan down for the main buses but i know i'll be redoing some of this as i add more sheets.

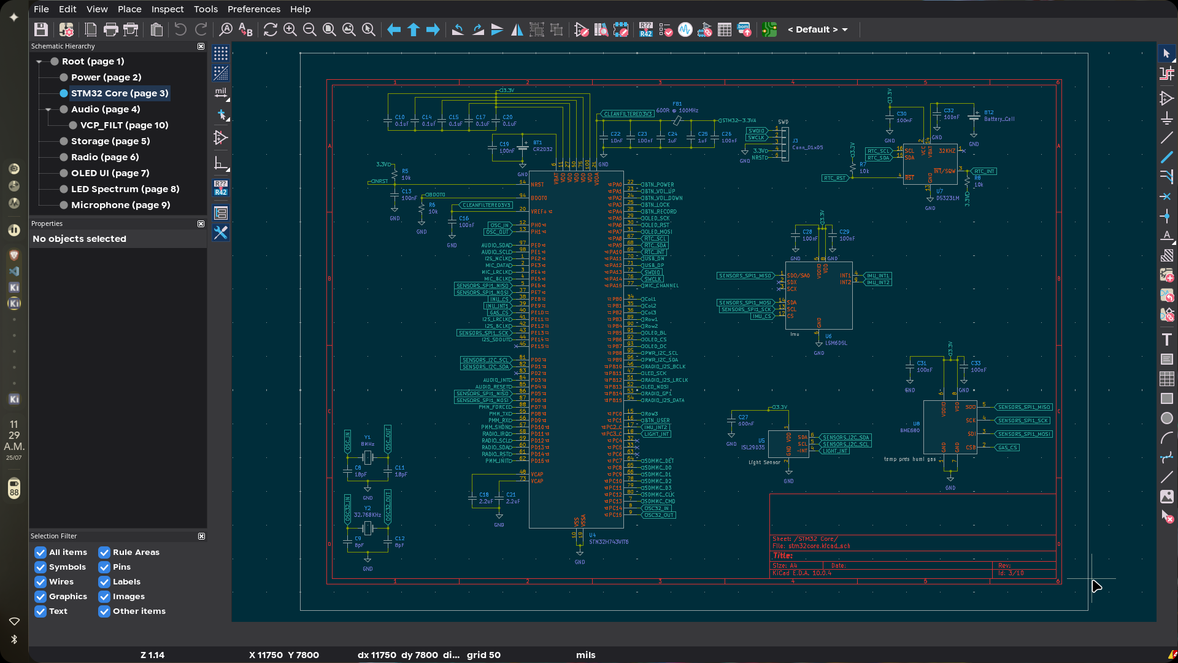
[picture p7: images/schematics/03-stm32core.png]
mcu core


**Total time spent: 5 hours**

# June 23: schematic - power and sensors

added the power section. usb-c connector with the cc resistors set up for ufp so the charger sees the board as a device. threw usblc6 esd protection on the data lines since usb is the thing that gets touched the most.

this is where i made my first big decision that i'd regret later. i was going to build a discrete power stage (separate charger + converters) but decided to go with a pmm module instead - an stm32-based module that handles charging, buck-boost, and power sequencing all in one. it sounded great on paper: less work for me, one module does everything, and it talks to the main mcu over uart/i2c for status and config. it has force-on, shutdown, and init pins for power control.

added the tps7a4701 ultra-low-noise ldo for the analog/audio supply and a tlv70233 for the digital 3.3v rail, so the analog side isn't fed from the same noisy rail as everything digital.

placed the sensors on the mcu core sheet. the lsm6dsl imu and bme680 share an spi bus with individual chip selects (cheap on pins, and neither needs continuous bandwidth). isl29035 light sensor went on its own i2c bus since it's so low bandwidth. i wanted the sensors off i2c to keep the i2c buses free for audio/radio control which is more timing sensitive.

power

**Total time spent: 6 hours**

# June 24: schematic - audio and radio

drew the audio section with the cs43131. it connects to sai1 for the i2s audio data and i2c4 for the control registers - i deliberately gave the dac its own i2c bus so tuning the radio or polling sensors never interferes with audio configuration.

added the vcp filter capacitor sub-circuit for the dac's charge pump. the cs43131 runs on an internal charge pump and those caps are critical for clean supply voltage, so i didn't cheap out on the values. headphone output has dc-blocking caps to keep dc off the headphones.

then the si4735 fm radio. this chip outputs i2s audio data directly, which is super convenient - it goes on sai2 so the radio and dac each have their own sai block and the mcu just switches the source. radio has its own i2c bus for tuning and control, plus an irq line for rds data ready (station name, metadata, etc).

added two antenna connectors with a solder jumper to pick between them - one for a whip antenna, one for an external/helical, because i wasn't sure yet which one the enclosure would fit. a solder jumper lets me decide later without a board spin.

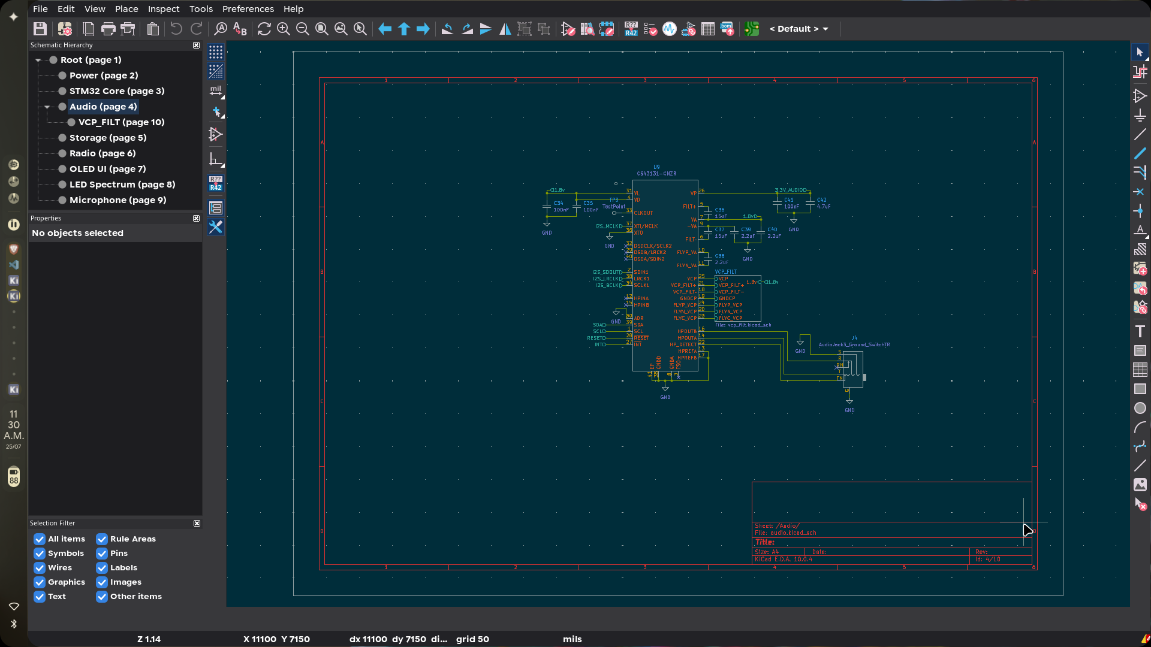
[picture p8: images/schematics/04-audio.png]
audio

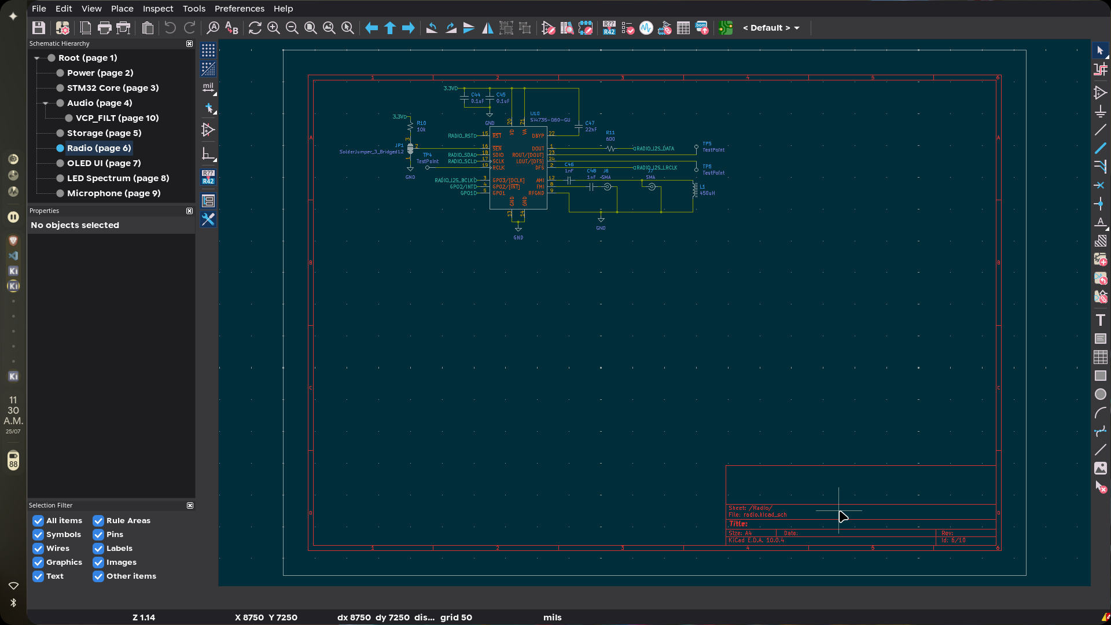
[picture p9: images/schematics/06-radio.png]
radio

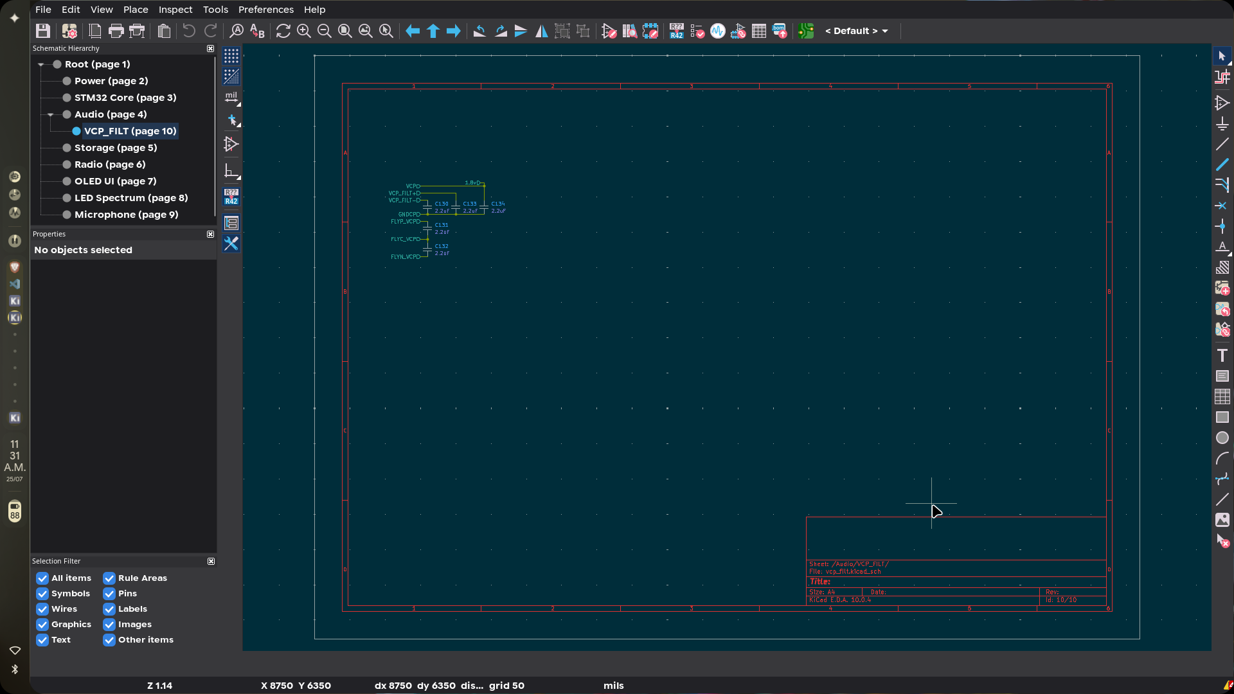
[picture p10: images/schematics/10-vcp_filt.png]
vcp filter


**Total time spent: 5 hours**

# June 25: schematic - storage, oled, microphone

added the micro sd card slot with the 4-bit sdmmc interface. 4-bit is noticeably faster than spi mode and the stm32h743 has a proper sdmmc peripheral so it's basically free. card detect on pc7 so firmware can watch for card insert/remove.

drew the oled display connector - an 8-pin header with spi interface. spi is plenty for a small display and leaves the i2c/sai buses free for audio.

designed the button matrix. 3x3 matrix for the main navigation buttons to save gpio, plus 6 direct buttons for power, volume, record, lock, boot0, and user. direct buttons for the ones that either need interrupts or can't tolerate scanning latency (power especially). added esd protection diodes on all the button inputs since buttons are a prime static entry point.

placed the ics-43434 mems microphone - it outputs i2s directly so it plugs into another sai block. it has a channel select pin so i can put it on the left or right channel, which gives flexibility for stereo/mono config later.

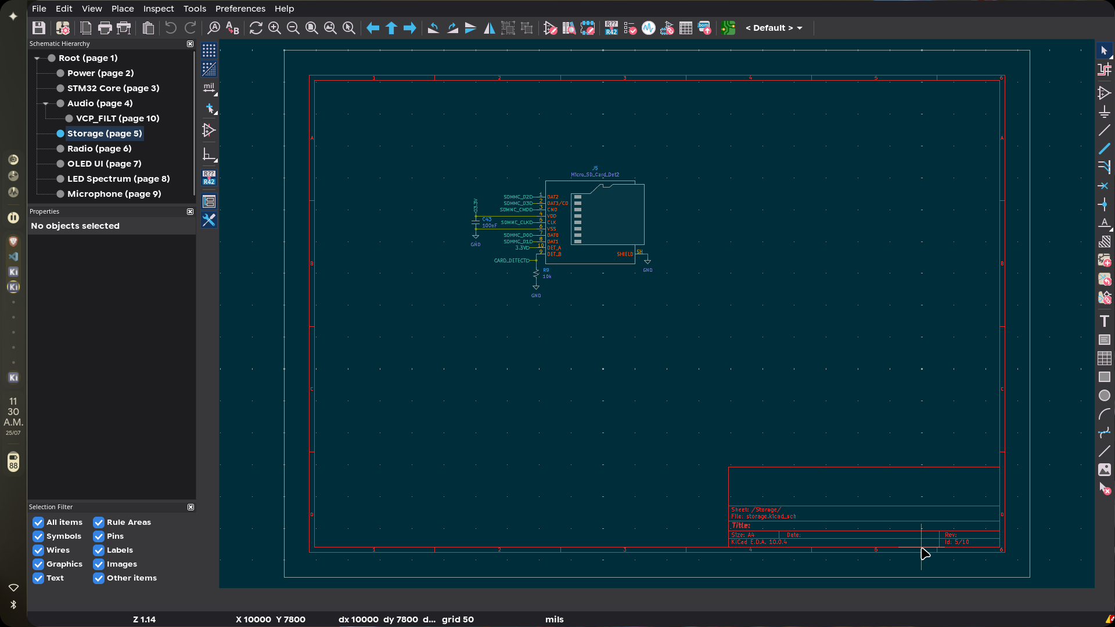
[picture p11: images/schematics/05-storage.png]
storage

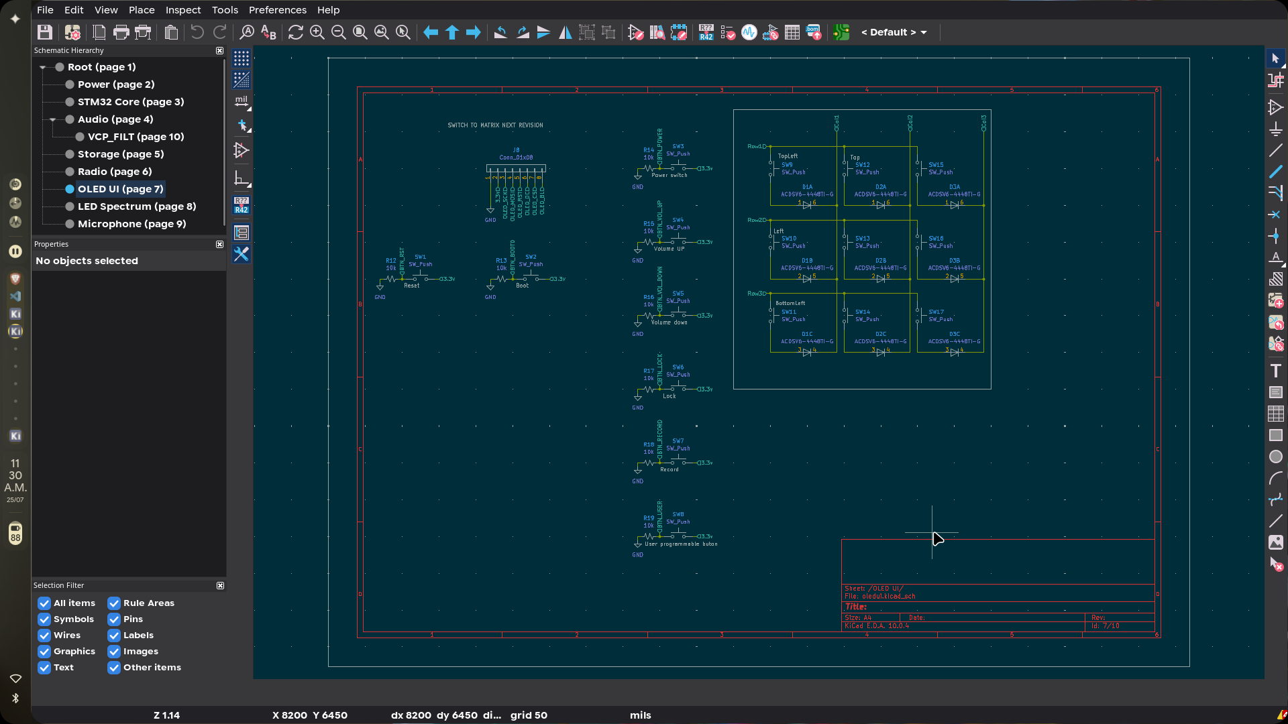
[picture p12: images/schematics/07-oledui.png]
oled ui

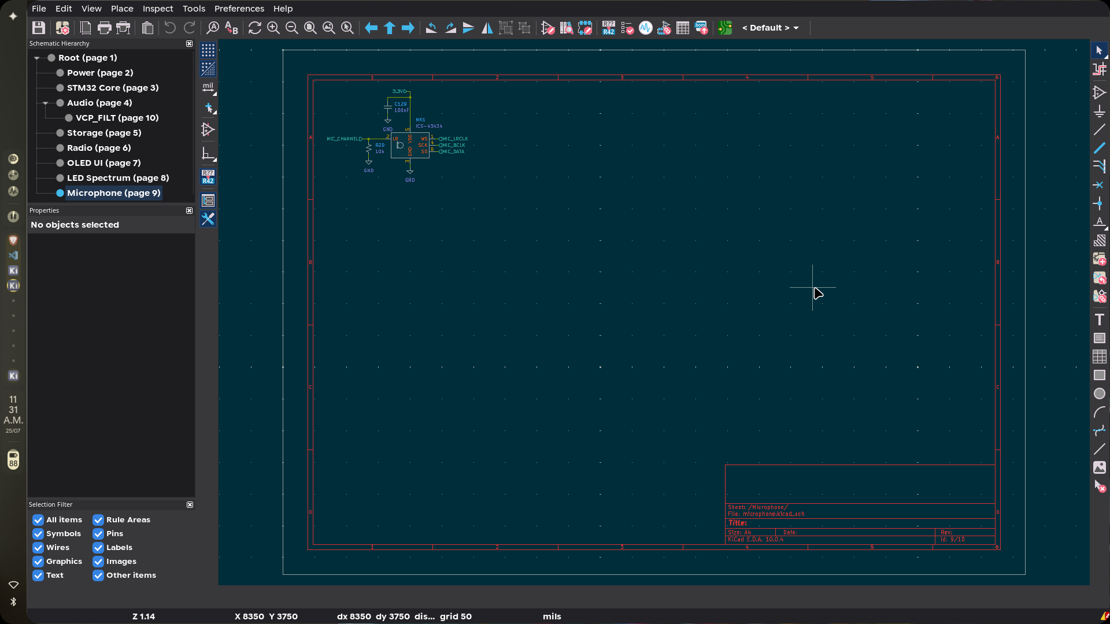
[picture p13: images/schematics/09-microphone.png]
microphone


**Total time spent: 5 hours**

# June 26: schematic - leds

added the apa102-2020 led arrays. 70 leds total split across two sheets - 35 for the sparkle effects and 35 for the spectrum analyzer bar. data lines are daisy-chained through all of them, so one data + one clock pin drives the whole lot.

each led gets a 100nf decoupling cap right next to it. with 70 leds that's 70 caps and this sheet probably took twice as long as any other just from the sheer number of components to place. all leds are powered from the 5v rail since apa102s have internal current regulation and 5v gives more headroom for accurate colors.

the data and clock lines come from two gpio pins bit-banging the apa102 protocol. i thought about using a hardware spi peripheral but the apa102 protocol isn't exactly spi, and bit-banging two pins on a 480mhz chip is plenty fast to drive the whole chain. it also keeps the real spi peripheral free for the oled and sensors.

definitely the most tedious sheet.

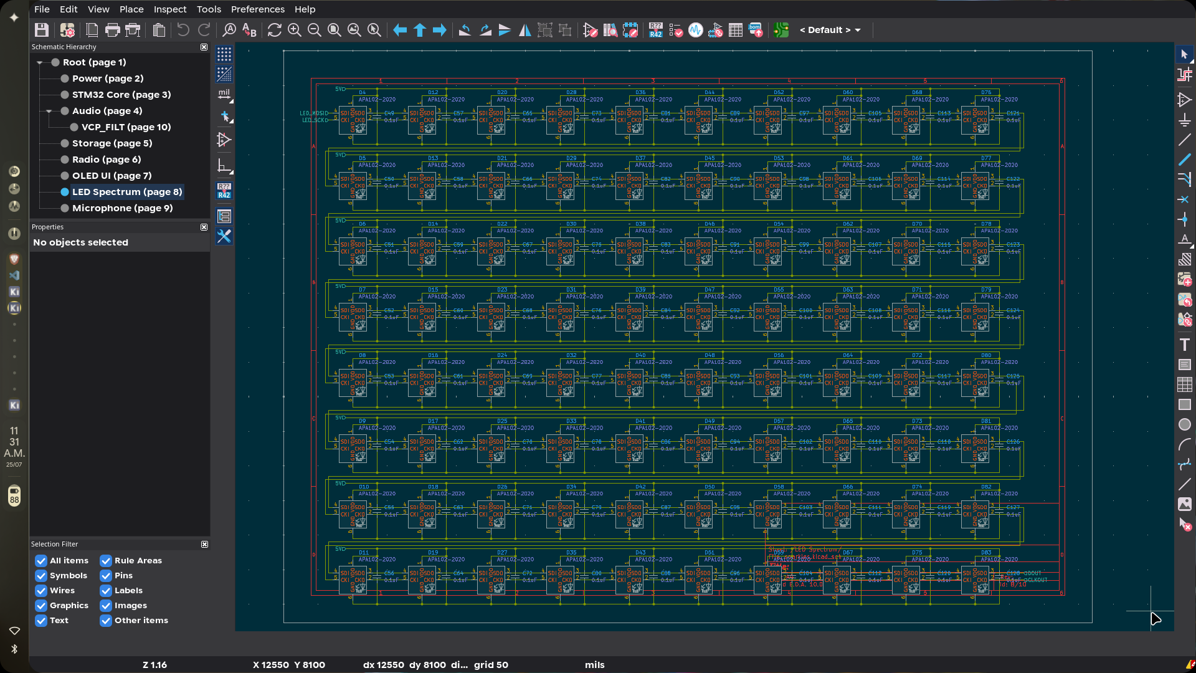
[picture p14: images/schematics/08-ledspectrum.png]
led spectrum


**Total time spent: 6 hours**

# June 28: schematic - pmm integration

started integrating the pmm module properly. it's an stm32-based module that handles battery charging, buck-boost conversion, and power sequencing. it communicates with the main mcu over uart for status and i2c for configuration, and has digital pins for force-on, shutdown, and init signals.

moved the pmm symbol to a better spot on the power sheet and started wiring up all 40 pins. 23 of them are no-connects (reserved pins, extra gpio, nrst, adc_in, fault, enable, pgood, and even a 3v3 output i wasn't using). it felt wrong leaving a third of the pins floating, but with a module like this you take what you're given.

this is where the pmm started to feel more like a burden than a help. every connection had to go through its pin mapping, i couldn't rename any of its signals, and i kept second-guessing the power sequencing.

pmm wiring

**Total time spent: 4 hours**

# June 29: schematic - pmm wiring and top-level

finished wiring the pmm module. connected all the signal pins - uart tx/rx, i2c sda/scl, shutdown, force, init. added hierarchical labels on the power sheet for everything going to the mcu core, and redesigned the top-level sheet pins to match the pmm's native signal names instead of the generic names i'd used before.

the power sheet now exposes 12 pins: +3.3v_audio, +3.3v_aux, force, init, scl, sda, shdn, swclk, swdio, uart_rx, uart_tx, vbus. connected the gnd pins on both sides to ground symbols and wired vbat+ and 5v_out to the appropriate rails.

the schematic was basically done after this - just needed a final review and drc pass. looking back, i should've done that review sooner, because the pmm turned out to be a mistake i'd rip out a few weeks later.

pmm done
top-level

**Total time spent: 5 hours**

# July 22: schematic review

full disclosure: there was a long gap here. i got busy with school stuff and didn't touch the project for weeks. the schematic just sat at "done" the whole time.

when i came back i did a careful review of all the sheets and it paid off immediately. caught a few net names that were inconsistent between sheets and fixed those. but the big one: the sensors sheet was missing its hierarchical labels, so it was essentially disconnected from the rest of the design. it would've been a nightmare to debug on the bench, and i only caught it because i actually clicked through every sheet instead of trusting that it worked.

spent the rest of the time running erc and tracing every net to make sure the connections were actually right. schematic is in good shape now, probably 95% complete.

schematic

**Total time spent: 3 hours**

# July 25: firmware skeleton

decided to start on the firmware while waiting for motivation to finish the schematic. nice change of pace from kicad.

set up a platformio project targeting the stm32h743vit6 with the stm32cube framework. wrote the full pin definitions header from the schematic - all 96 pins mapped to their alternate functions.

configured the system clock at 480mhz from the 8mhz hse crystal using pll1. that's the stm32h7 clocking rabbit hole - there are like 3 plls and a whole routing matrix, and i definitely read the reference manual too many times. set up pll2 for audio clock generation too, so the sai can run at a clean multiple for the dac.

initialized all the i2c buses (sensors, pmm, rtc, audio), spi buses (oled, sensors), and uart (pmm debug). wrote the hal msp callbacks for pin muxing on all the peripherals, and gpio init sets up all the button inputs, chip selects, control outputs, and sd card detect.

firmware compiles clean - 14.9kb flash, 2.3kb ram used. basically an empty shell, but it proves the clock, buses, and pins are all configured right. also wrote the readme for both the firmware and the full project, and created this journal.

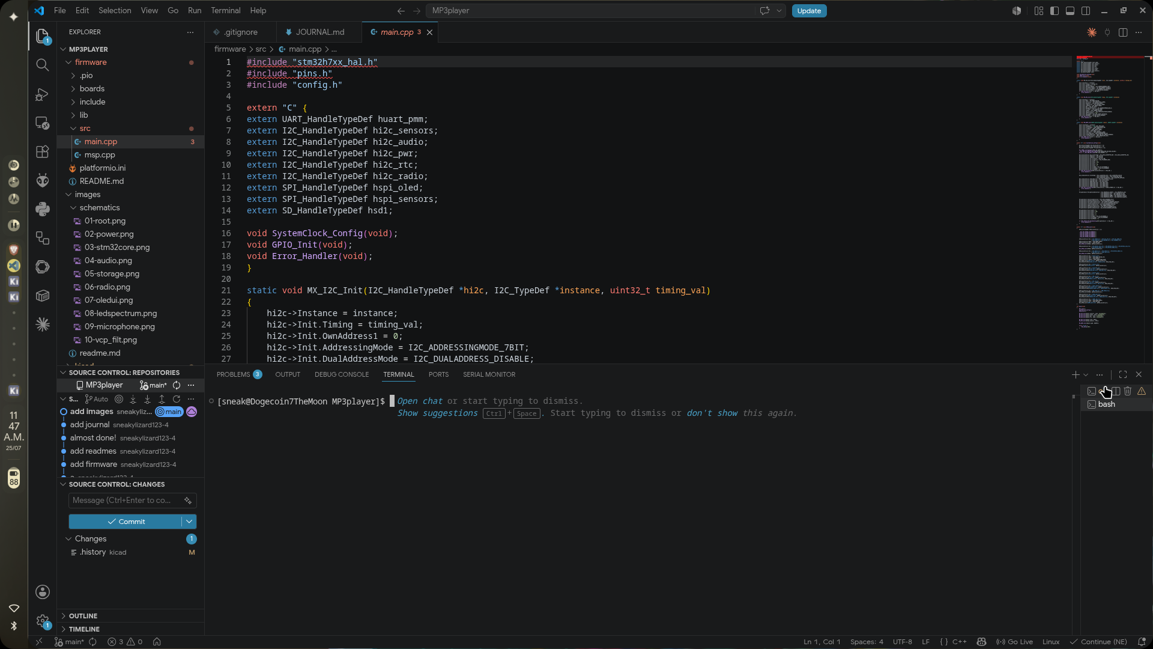
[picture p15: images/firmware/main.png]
main.cpp


**Total time spent: 4 hours**

# July 26: schematic rework

major rework of the power section. ditched the pmm module entirely - the more i thought about it, the more it was overkill for what we actually need. it added a whole extra mcu and a uart/i2c protocol just to do what a couple of dedicated chips do more simply. simpler to understand, cheaper, and fewer ways to fail.

replaced it with a discrete bq24090 battery charger (1a single-cell li-ion) with ntc thermistor monitoring and a charge led. added a tps613222adbv boost converter to step the battery up to 5v for the apa102 leds. kept the tps7a4701 and tlv70233 regulators for the analog and digital 3.3v rails.

the power sheet is much simpler now - just 3 pins out: +3.3v_audio, +3.3v_aux, and vbus. no more uart/i2c control interface, no more sequencing pins.

while i was at it i cleaned up a bunch of other stuff: removed the cr2032 battery cell and its backup circuitry from the mcu core sheet (the rtc just runs off the main battery when the device is on - one less thing to change), merged the sensors into the stm32core sheet directly, removed the vcp filter sheet (those caps are now inline on the power sheet), renamed the sparkles sheet to led spectrum and simplified it heavily, changed the crystal load caps from 18pf to 12pf for better stability, swapped testpoints for mounting holes on the root sheet, and changed the button switches to acdsv6-4448ti-g tactile switches.

schematic is now 8 sheets, down from 12. much cleaner.

power rework
root overview

**Total time spent: 5 hours**

# July 27: pcb layout

laid out the board in kicad. 6-layer stackup with 2 internal power planes, 1.6mm thickness, roughly 50x70mm for a portable handheld player. the extra layers were a bit of a luxury but they make routing so much easier and keep the supply impedance low.

routed the high-speed interfaces first - sdmmc for the sd card, sai/i2s for audio and mic, and the usb differential pair. i figured if those couldn't get clean routes i'd need to rethink pin assignments before doing anything else.

kept the analog audio section separated from the digital and power sections, and placed the cs43131 dac close to the headphone jack to keep the analog trace lengths short. the bq24090 charger and tps613222adbv boost went in the power section with thermal pad stitching under the chips. apa102 leds are arranged along the bottom and right edges for the spectrum bar, oled connector at the top edge for a flip-up screen, and the button matrix routed through the center.

mounting holes in the corners for the enclosure. ran a full drc pass at the end - all clearance and creepage rules pass, no unconnected nets. felt like a real milestone.

pcb front
pcb back

**Total time spent: 6 hours**

# July 28: pcb silkscreen

fixed up the silkscreen layer - a bunch of reference designators were overlapping and unreadable, so i adjusted text sizes and positions across the whole board. added a penguin easter egg on the bottom copper layer, visible through the solder mask. clearly the most important part of the project.

kicad keeps crashing every few minutes, probably due to wayland rendering issues. had to save after basically every change, which drove me insane.

ran a final design rule check - all clear - and did a 3d render to check the board appearance. pcb is ready for fabrication.

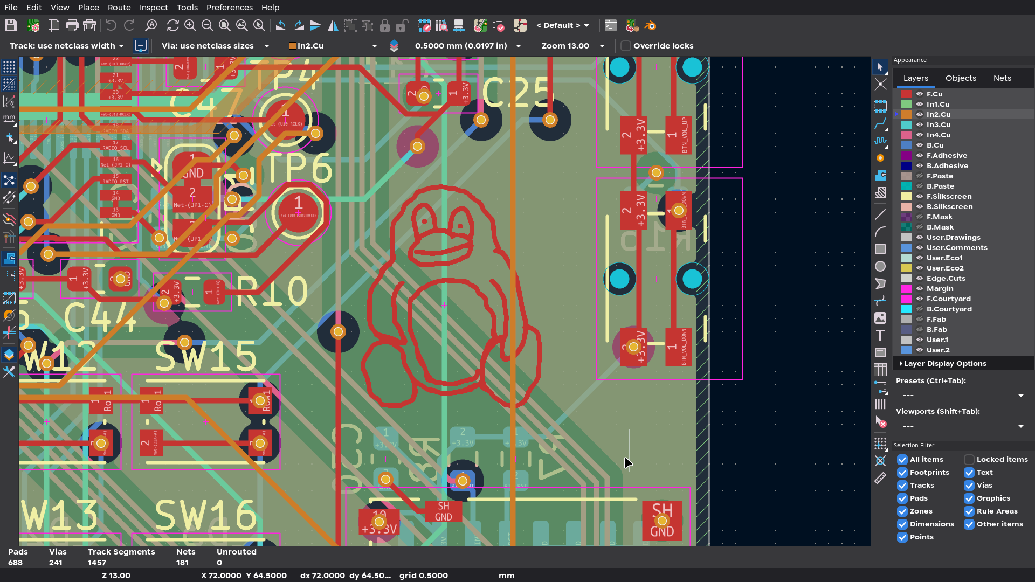
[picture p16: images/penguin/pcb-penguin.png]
penguin

penguin2

**Total time spent: 1 hour**

# July 29: cart

started the bom export and lcsc part picking. exported the bom from kicad and started hunting down every part on lcsc.

had to change the antenna inductor because there are no 450uh 0805 signal inductors - switched to a 1206 470uh to match common values. this kind of thing happens a lot when sourcing: the schematic value is fine but nobody stocks it in that package, so you adjust and move on.

kicad isn't crashing anymore?? not complaining.

bom is a little expensive though, so i'll need to swap in parts i might already have in the parts drawer and find some cheaper equivalents.

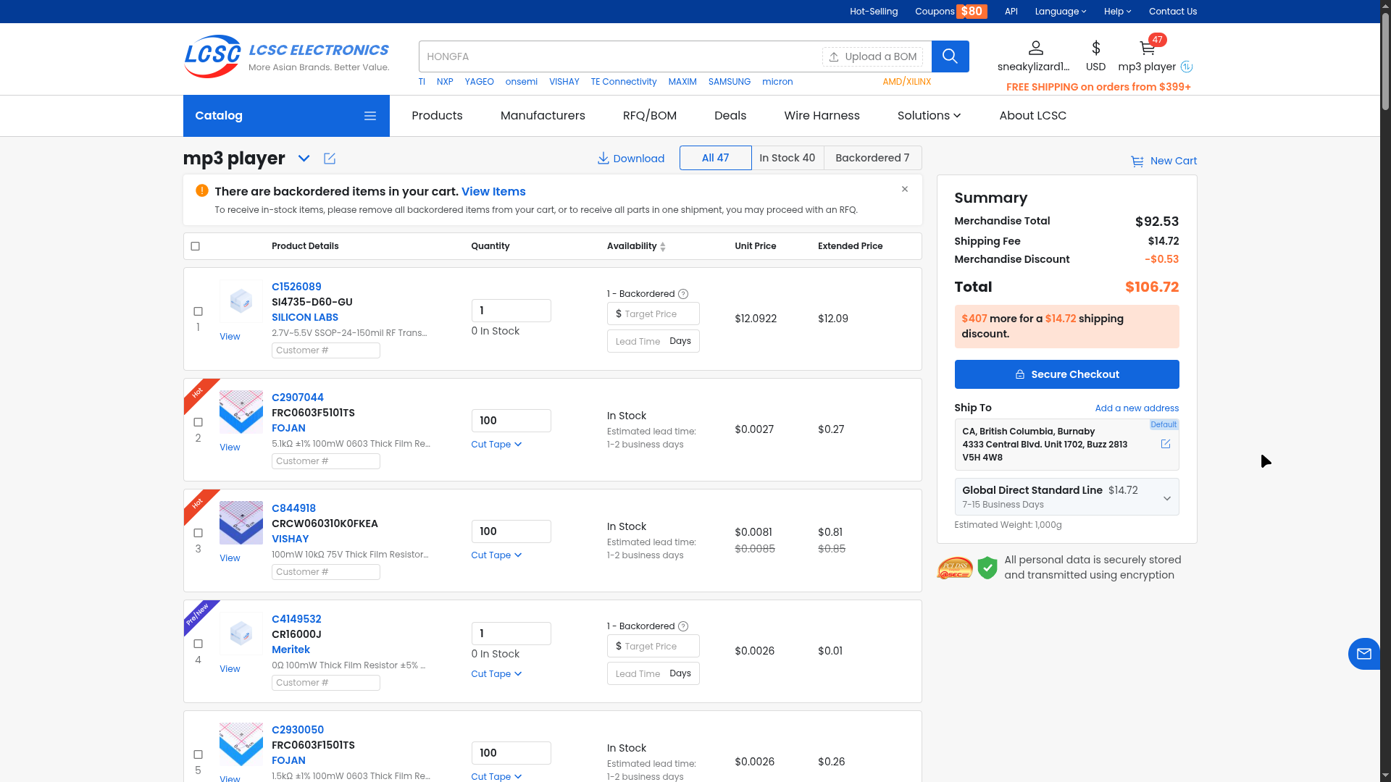
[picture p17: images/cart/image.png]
cart


**Total time spent: 2 hours**

# July 30: trace fixes

went back and re-examined the routing. some traces were quite wobbly from when i first routed them and weren't great for high-speed signals - lots of unnecessary zigzags that add stub length and impedance discontinuities.

the fix took a while because there are lots of vias on the pcb and every straight line had to thread between them. i went trace by trace through the sdmmc and i2s lines especially, and they're reasonably straight now with way less wobble.

honestly this was quite therapeutic and relaxing. 9/10 activity, would recommend.

pcb

**Total time spent: 2 hours**

# July 31: via optimisation

optimized via placement to free up space and make room for traces. a lot of vias were just dropped wherever they landed, so i moved them into tidy columns and out of the way of routing channels, and trimmed the ones i didn't need.

added some extra vias to help with emi near the power stage - stitching vias around the boost converter's switching area so return currents have a low-impedance path. might add some more near the audio and radio stages too, i'll see how it looks on the next review.

pcb

**Total time spent: 3 hours**

# August 1: readme polish

fixed the readme as specified by reviewers - they wanted it to explain what the sensors actually do and to follow the readme guide. added an overview and gallery to the readme along with assembly and firmware instructions, and made sure the bom table was in there.

firmware

**Total time spent: 1 hour**

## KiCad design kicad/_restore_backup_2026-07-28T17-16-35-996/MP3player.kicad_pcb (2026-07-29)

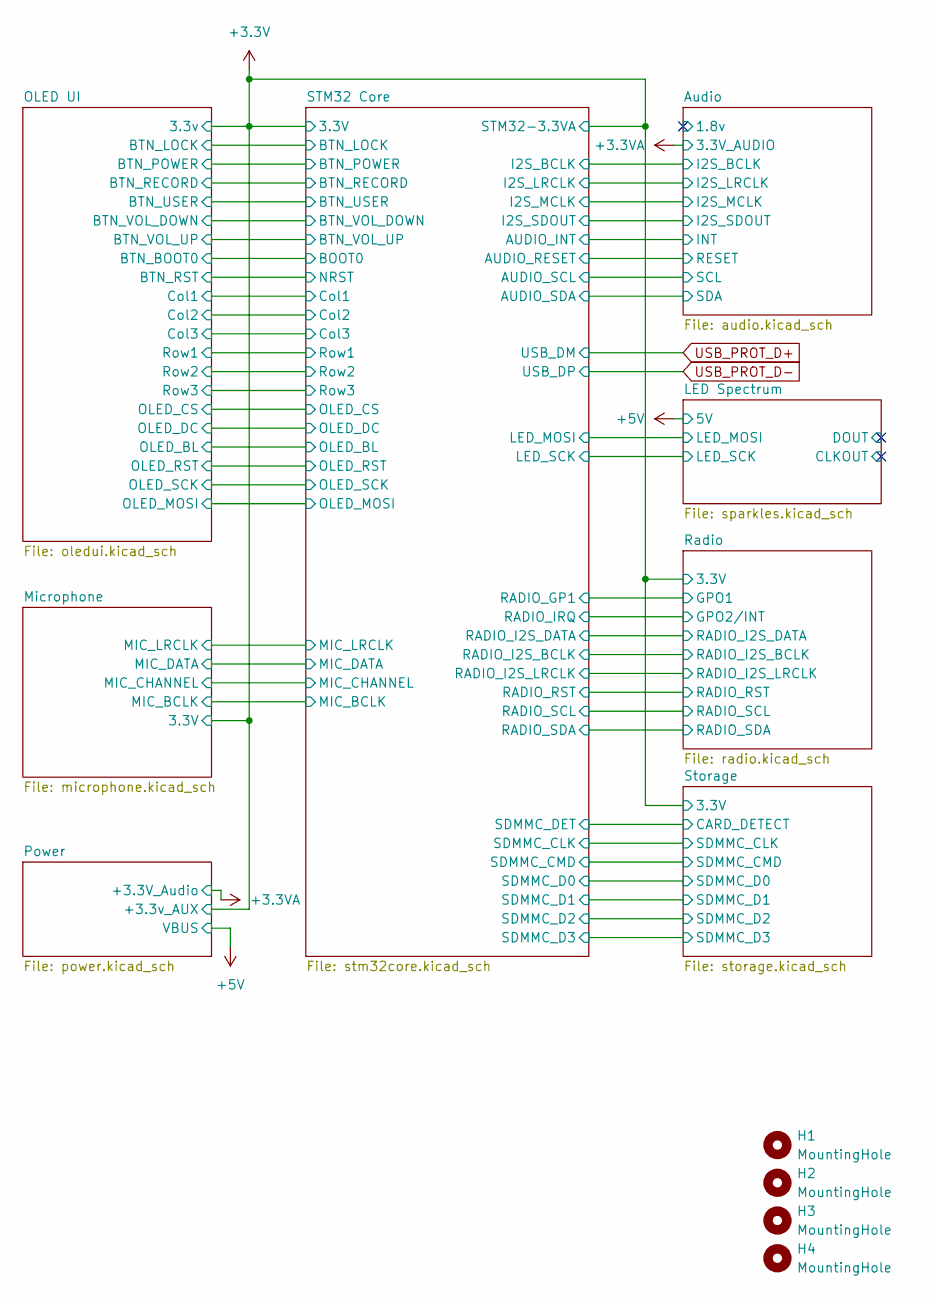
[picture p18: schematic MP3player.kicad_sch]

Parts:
H1, H2, H3, H4: MountingHole; MountingHole_3.2mm_M3

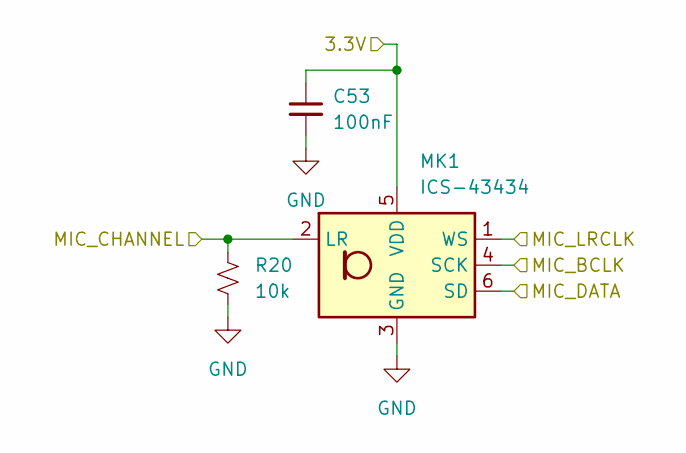
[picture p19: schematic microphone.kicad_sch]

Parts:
C53: 100nF; C_0603_1608Metric
MK1: ICS-43434; InvenSense_ICS-43434-6_3.5x2.65mm
R20: 10k; R_0603_1608Metric

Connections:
+3.3V: C53.1, MK1.5 (VDD); also elsewhere on the board
/Microphone/MIC_BCLK: MK1.4 (SCK); also elsewhere on the board
/Microphone/MIC_CHANNEL: MK1.2 (LR), R20.1; also elsewhere on the board
/Microphone/MIC_DATA: MK1.6 (SD); also elsewhere on the board
/Microphone/MIC_LRCLK: MK1.1 (WS); also elsewhere on the board
GND: C53.2, MK1.3 (GND), R20.2; also elsewhere on the board

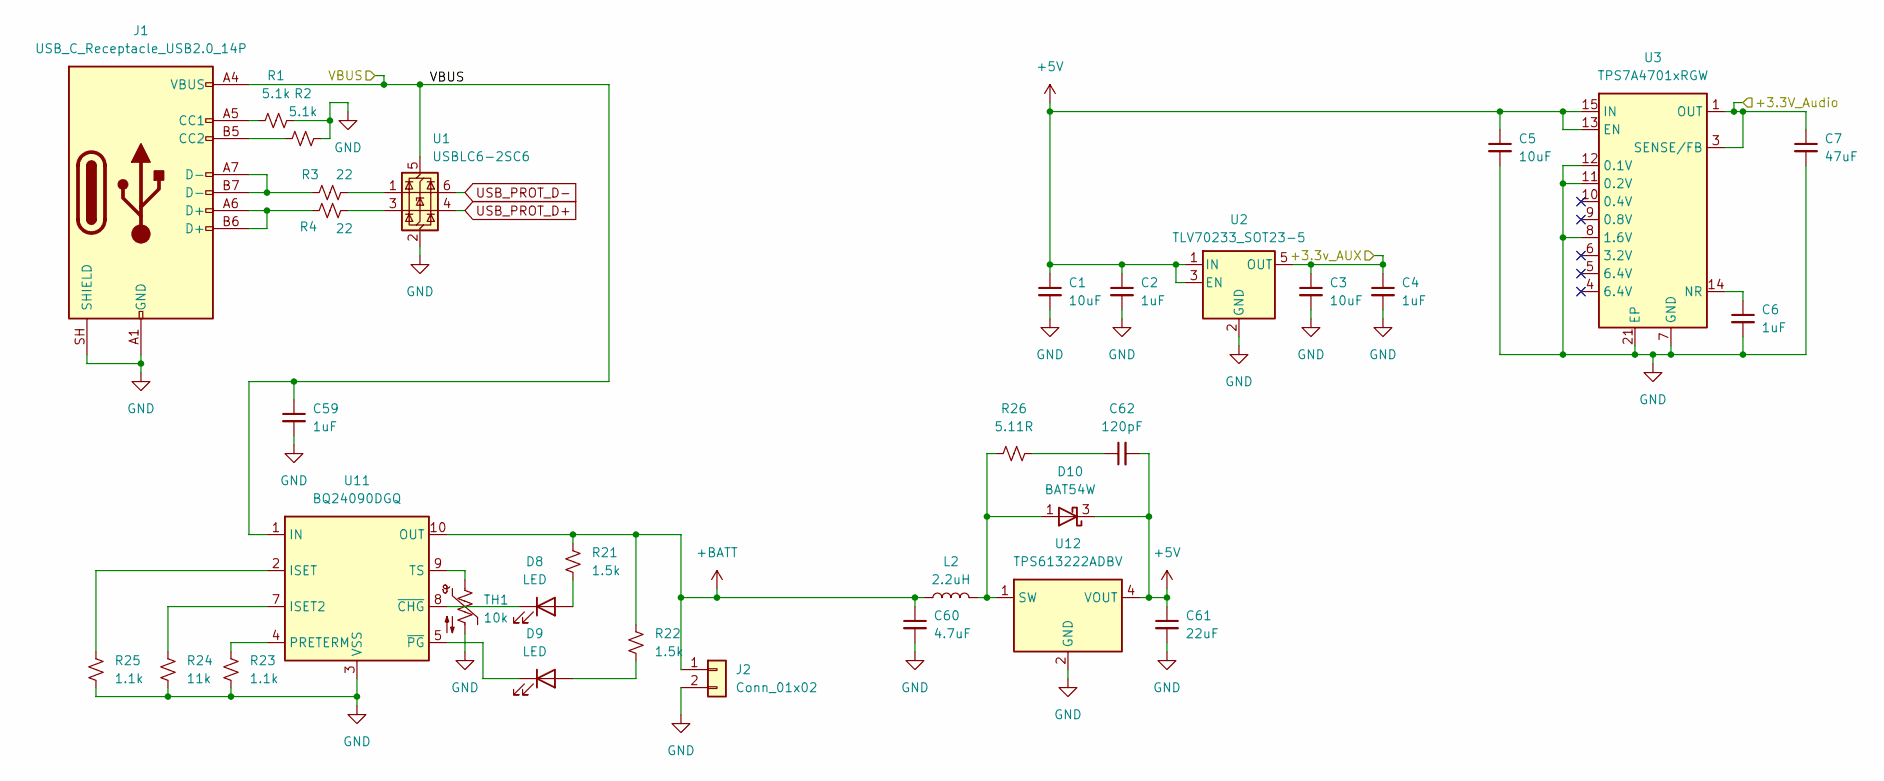
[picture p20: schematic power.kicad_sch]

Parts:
C1, C3, C5: 10uF; C_0603_1608Metric
C2, C4, C6, C59: 1uF; C_0603_1608Metric
C7: 47uF; C_0603_1608Metric
C60: 4.7uF; C_0603_1608Metric
C61: 22uF; C_0603_1608Metric
C62: 120pF; C_0603_1608Metric
D8, D9: LED; LED_0603_1608Metric
D10: BAT54W; SOT-323_SC-70
J1: USB_C_Receptacle_USB2.0_14P; USB_C_Receptacle_HRO_TYPE-C-31-M-12
J2: Conn_01x02; JST_PH_B2B-PH-K_1x02_P2.00mm_Vertical
L2: 2.2uH; L_0805_2012Metric
R1, R2: 5.1k; R_0603_1608Metric
R3, R4: 22; R_0603_1608Metric
R21, R22: 1.5k; R_0603_1608Metric
R23, R25: 1.1k; R_0603_1608Metric
R24: 11k; R_0603_1608Metric
R26: 5.11R; R_0603_1608Metric
TH1: 10k; R_0603_1608Metric
U1: USBLC6-2SC6; SOT-23-6
U2: TLV70233_SOT23-5; SOT-23-5
U3: TPS7A4701xRGW; Texas_RGW0020A_VQFN-20-1EP_5x5mm_P0.65mm_EP3.15x3.15mm_Ther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
U11: BQ24090DGQ; HVSSOP-10-1EP_3x3mm_P0.5mm_EP1.83x1.89mm
U12: TPS613222ADBV; SOT-23-5

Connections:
+3.3V: C3.1, C4.1, U2.5 (OUT); also elsewhere on the board
+3.3VA: C7.1, U3.1 (OUT), U3.3 (SENSE/FB), U3.20 (OUT); also elsewhere on the board
+5V: C1.1, C2.1, C5.1, C59.1, C61.1, C62.2, D10.3 (K), J1.A4 (VBUS), J1.A9 (VBUS), J1.B4 (VBUS), J1.B9 (VBUS), U1.5 (VBUS), U2.1 (IN), U2.3 (EN), U3.13 (EN), U3.15 (IN), U3.16 (IN), U11.1 (IN), U12.4 (VOUT); also elsewhere on the board
+BATT: C60.1, J2.1, L2.1, R21.1, R22.1, U11.10 (OUT); also elsewhere on the board
GND: C1.2, C2.2, C3.2, C4.2, C5.2, C6.2, C7.2, C59.2, C60.2, C61.2, J1.A1 (GND), J1.A12 (GND), J1.B1 (GND), J1.B12 (GND), J1.SH (SHIELD), J2.2, R1.2, R2.2, R23.2, R24.2, R25.2, TH1.2, U1.2 (GND), U2.2 (GND), U3.7 (GND), U3.8 (1.6V), U3.11 (0.2V), U3.12 (0.1V), U3.21 (EP), U11.3 (VSS), U11.11 (VSS), U12.2 (GND); also elsewhere on the board
unnamed: C62.1, R26.2
unnamed: D8.2 (A), R21.2
unnamed: D8.1 (K), U11.8 (~CHG)
unnamed: D9.2 (A), R22.2
unnamed: D9.1 (K), U11.5 (~PG)
unnamed: D10.1 (A), L2.2, R26.1, U12.1 (SW)
unnamed: J1.A5 (CC1), R1.1
unnamed: J1.B5 (CC2), R2.1
unnamed: J1.A6 (D+), J1.B6 (D+), R4.1
unnamed: J1.A7 (D-), J1.B7 (D-), R3.1
unnamed: R3.2, U1.1 (I/O1)
unnamed: R4.2, U1.3 (I/O2)
unnamed: C6.1, U3.14 (NR)
unnamed: R24.1, U11.7 (ISET2)
unnamed: R25.1, U11.2 (ISET)
unnamed: R23.1, U11.4 (PRETERM)
unnamed: TH1.1, U11.9 (TS)
USB_PROT_D+: U1.4 (I/O2); also elsewhere on the board
USB_PROT_D-: U1.6 (I/O1); also elsewhere on the board

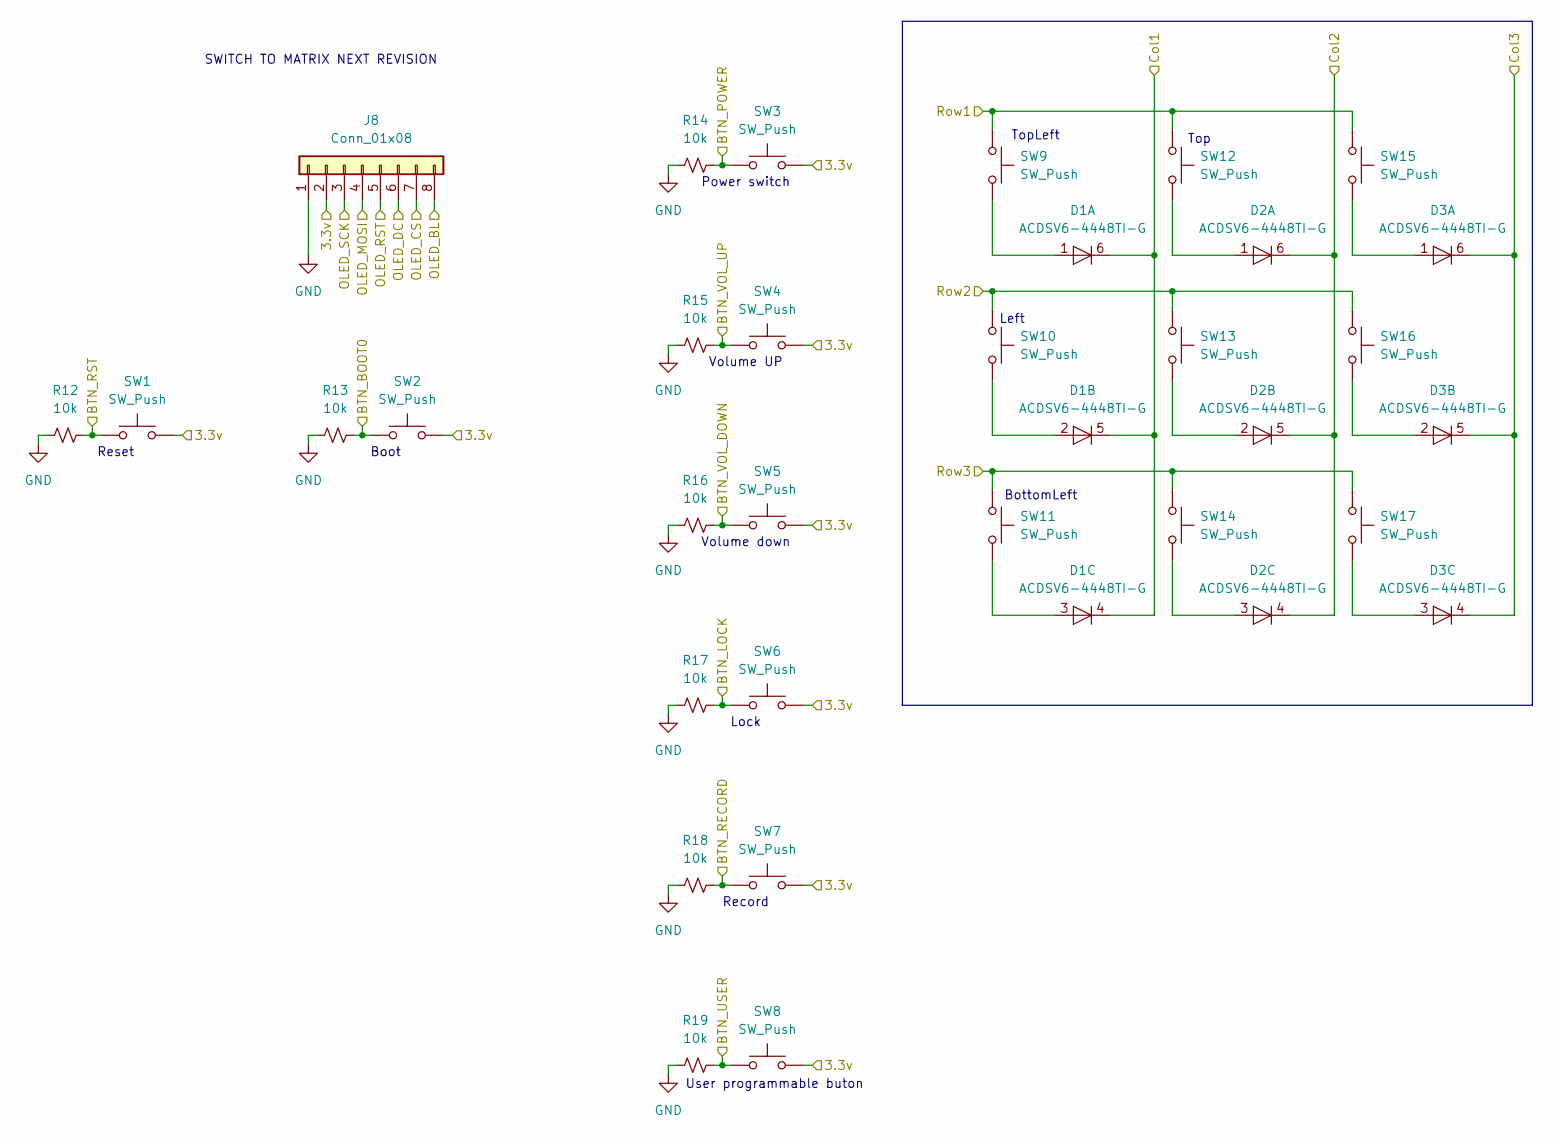
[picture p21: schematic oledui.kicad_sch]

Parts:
D1, D2, D3: ACDSV6-4448TI-G; SOT-363_SC-70-6
J8: Conn_01x08; PinHeader_1x08_P2.54mm_Vertical_SMD_Pin1Right
R12, R13, R14, R15, R16, R17, R18, R19: 10k; R_0603_1608Metric
SW1, SW2, SW3, SW4, SW5, SW6, SW7, SW8: SW_Push; Panasonic_EVQPUM_EVQPUD
SW9, SW10, SW11, SW12, SW13, SW14, SW15, SW16, SW17: SW_Push; SW_Push_1P1T_NO_CK_KMR2

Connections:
+3.3V: J8.2, SW1.2, SW2.2, SW3.2, SW4.2, SW5.2, SW6.2, SW7.2, SW8.2; also elsewhere on the board
/OLED UI/BTN_BOOT0: R13.2, SW2.1; also elsewhere on the board
/OLED UI/BTN_LOCK: R17.2, SW6.1; also elsewhere on the board
/OLED UI/BTN_POWER: R14.2, SW3.1; also elsewhere on the board
/OLED UI/BTN_RECORD: R18.2, SW7.1; also elsewhere on the board
/OLED UI/BTN_RST: R12.2, SW1.1; also elsewhere on the board
/OLED UI/BTN_USER: R19.2, SW8.1; also elsewhere on the board
/OLED UI/BTN_VOL_DOWN: R16.2, SW5.1; also elsewhere on the board
/OLED UI/BTN_VOL_UP: R15.2, SW4.1; also elsewhere on the board
/OLED UI/Col1: D1.4 (K), D1.5 (K), D1.6 (K); also elsewhere on the board
/OLED UI/Col2: D2.4 (K), D2.5 (K), D2.6 (K); also elsewhere on the board
/OLED UI/Col3: D3.4 (K), D3.5 (K), D3.6 (K); also elsewhere on the board
/OLED UI/OLED_BL: J8.8; also elsewhere on the board
/OLED UI/OLED_CS: J8.7; also elsewhere on the board
/OLED UI/OLED_DC: J8.6; also elsewhere on the board
/OLED UI/OLED_MOSI: J8.4; also elsewhere on the board
/OLED UI/OLED_RST: J8.5; also elsewhere on the board
/OLED UI/OLED_SCK: J8.3; also elsewhere on the board
/OLED UI/Row1: SW9.1, SW12.1, SW15.1; also elsewhere on the board
/OLED UI/Row2: SW10.1, SW13.1, SW16.1; also elsewhere on the board
/OLED UI/Row3: SW11.1, SW14.1, SW17.1; also elsewhere on the board
GND: J8.1, R12.1, R13.1, R14.1, R15.1, R16.1, R17.1, R18.1, R19.1; also elsewhere on the board
unnamed: D1.1 (A), SW9.2
unnamed: D1.2 (A), SW10.2
unnamed: D1.3 (A), SW11.2
unnamed: D2.1 (A), SW12.2
unnamed: D2.2 (A), SW13.2
unnamed: D2.3 (A), SW14.2
unnamed: D3.1 (A), SW15.2
unnamed: D3.2 (A), SW16.2
unnamed: D3.3 (A), SW17.2

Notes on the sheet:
Record
Top
User programmable buton
SWITCH TO MATRIX NEXT REVISION
BottomLeft
Volume down
Boot
Left
Volume UP
Reset
Power switch
TopLeft
Lock

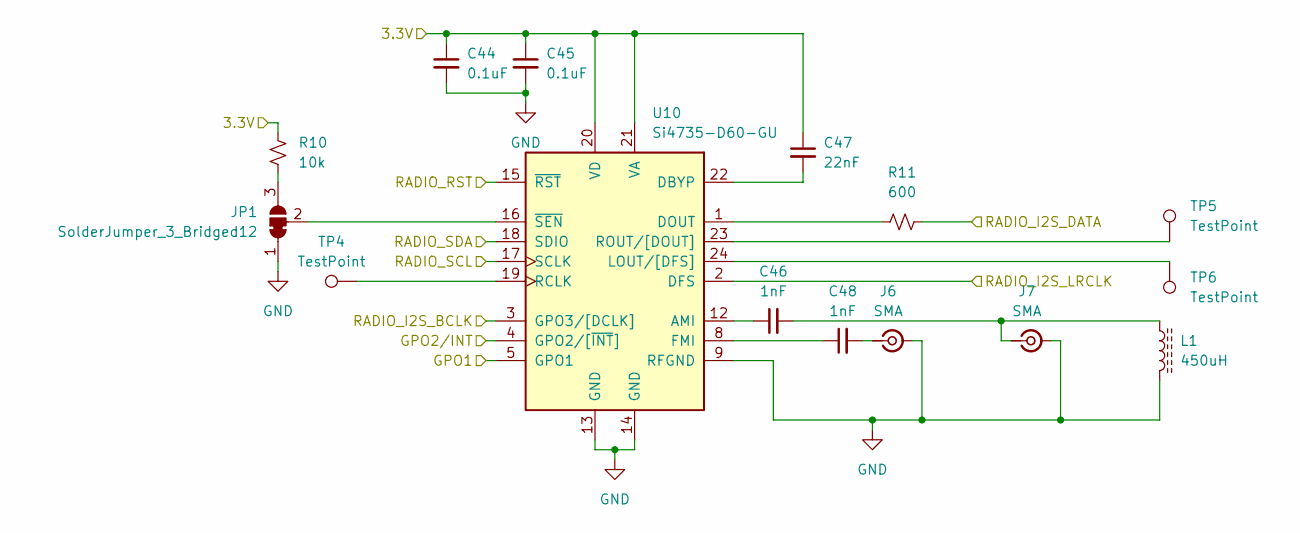
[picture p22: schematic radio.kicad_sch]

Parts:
C44, C45: 0.1uF; C_0603_1608Metric
C46, C48: 1nF; C_0603_1608Metric
C47: 22nF; C_0603_1608Metric
J6, J7: SMA; SMA_Amphenol_901-143_Horizontal
JP1: SolderJumper_3_Bridged12; SolderJumper-3_P1.3mm_Bridged12_RoundedPad1.0x1.5mm
L1: 450uH; L_0805_2012Metric
R10: 10k; R_0603_1608Metric
R11: 600; R_0603_1608Metric
TP4, TP5, TP6: TestPoint; TestPoint_Pad_D1.5mm
U10: Si4735-D60-GU; SSOP-24_3.9x8.7mm_P0.635mm

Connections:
+3.3V: C44.1, C45.1, C47.1, R10.2, U10.20 (VD), U10.21 (VA); also elsewhere on the board
/Radio/GPO1: U10.5 (GPO1); also elsewhere on the board
/Radio/GPO2/INT: U10.4 (GPO2/[~INT]); also elsewhere on the board
/Radio/RADIO_I2S_BCLK: U10.3 (GPO3/[DCLK]); also elsewhere on the board
/Radio/RADIO_I2S_DATA: R11.2; also elsewhere on the board
/Radio/RADIO_I2S_LRCLK: U10.2 (DFS); also elsewhere on the board
/Radio/RADIO_RST: U10.15 (~RST); also elsewhere on the board
/Radio/RADIO_SCL: U10.17 (SCLK); also elsewhere on the board
/Radio/RADIO_SDA: U10.18 (SDIO); also elsewhere on the board
GND: C44.2, C45.2, J6.2 (Ext), J7.2 (Ext), JP1.1 (A), L1.2, U10.9 (RFGND), U10.13 (GND), U10.14 (GND); also elsewhere on the board
unnamed: C48.2, J6.1 (In)
unnamed: C46.2, J7.1 (In), L1.1
unnamed: JP1.3 (B), R10.1
unnamed: JP1.2 (C), U10.16 (~SEN)
unnamed: C46.1, U10.12 (AMI)
unnamed: C47.2, U10.22 (DBYP)
unnamed: R11.1, U10.1 (DOUT)
unnamed: C48.1, U10.8 (FMI)
unnamed: TP6.1 (1_1), U10.24 (LOUT/[DFS])
unnamed: TP4.1 (1_1), U10.19 (RCLK)
unnamed: TP5.1 (1_1), U10.23 (ROUT/[DOUT])

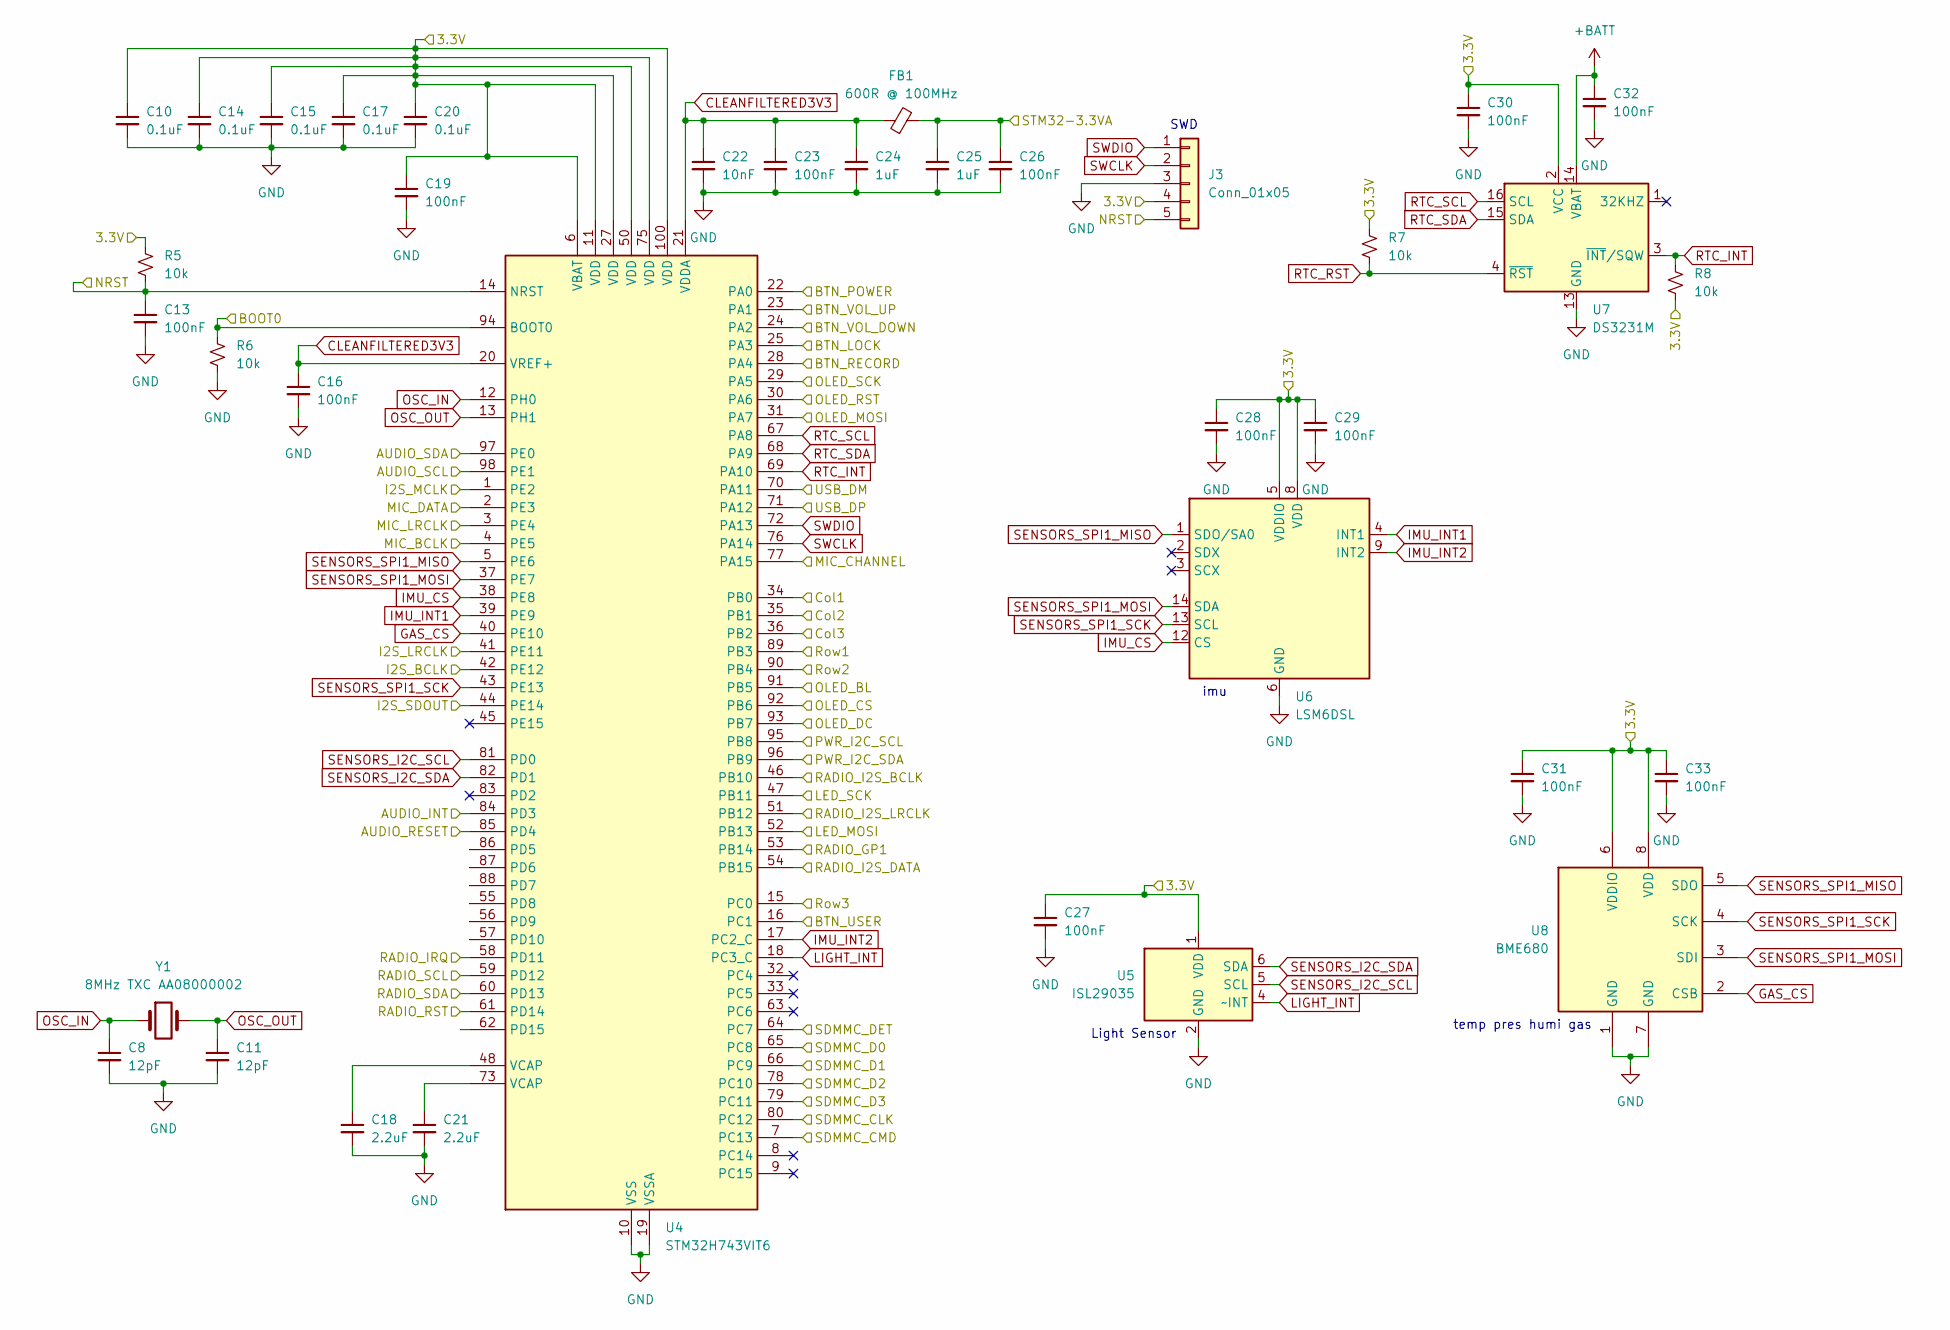
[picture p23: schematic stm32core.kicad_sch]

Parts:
C8, C11: 12pF; C_0603_1608Metric
C10, C14, C15, C17, C20: 0.1uF; C_0603_1608Metric
C13, C16, C19, C23, C26, C27, C28, C29, C30, C31, C32, C33: 100nF; C_0603_1608Metric
C18, C21: 2.2uF; C_0603_1608Metric
C22: 10nF; C_0603_1608Metric
C24, C25: 1uF; C_0603_1608Metric
FB1: 600R @ 100MHz; L_0603_1608Metric
J3: Conn_01x05; PinHeader_1x05_P2.54mm_Vertical
R5, R6, R7, R8: 10k; R_0603_1608Metric
U4: STM32H743VIT6; LQFP-100_14x14mm_P0.5mm
U5: ISL29035; Renesas_DFN-6_1.5x1.6mm_P0.5mm
U6: LSM6DSL; LGA-14_3x2.5mm_P0.5mm_LayoutBorder3x4y
U7: DS3231M; SOIC-16W_7.5x10.3mm_P1.27mm
U8: BME680; Bosch_LGA-8_3x3mm_P0.8mm_ClockwisePinNumbering
Y1: 8MHz TXC AA08000002; Crystal_SMD_5032-2Pin_5.0x3.2mm

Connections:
+3.3V: C10.1, C14.1, C15.1, C17.1, C19.1, C20.1, C25.1, C26.1, C27.1, C28.1, C29.1, C30.1, C31.1, C33.1, FB1.2, J3.4, R5.1, R7.1, R8.2, U4.6 (VBAT), U4.11 (VDD), U4.27 (VDD), U4.50 (VDD), U4.75 (VDD), U4.100 (VDD), U5.1 (VDD), U6.5 (VDDIO), U6.8 (VDD), U7.2 (VCC), U8.6 (VDDIO), U8.8 (VDD); also elsewhere on the board
+BATT: C32.1, U7.14 (VBAT); also elsewhere on the board
/Audio/I2S_BCLK: U4.42 (PE12); also elsewhere on the board
/Audio/I2S_LRCLK: U4.41 (PE11); also elsewhere on the board
/Audio/I2S_MCLK: U4.1 (PE2); also elsewhere on the board
/Audio/I2S_SDOUT: U4.44 (PE14); also elsewhere on the board
/Audio/INT: U4.84 (PD3); also elsewhere on the board
/Audio/RESET: U4.85 (PD4); also elsewhere on the board
/Audio/SCL: U4.98 (PE1); also elsewhere on the board
/Audio/SDA: U4.97 (PE0); also elsewhere on the board
/LED Spectrum/LED_MOSI: U4.52 (PB13); also elsewhere on the board
/LED Spectrum/LED_SCK: U4.47 (PB11); also elsewhere on the board
/Microphone/MIC_BCLK: U4.4 (PE5); also elsewhere on the board
/Microphone/MIC_CHANNEL: U4.77 (PA15); also elsewhere on the board
/Microphone/MIC_DATA: U4.2 (PE3); also elsewhere on the board
/Microphone/MIC_LRCLK: U4.3 (PE4); also elsewhere on the board
/OLED UI/BTN_BOOT0: R6.1, U4.94 (BOOT0); also elsewhere on the board
/OLED UI/BTN_LOCK: U4.25 (PA3); also elsewhere on the board
/OLED UI/BTN_POWER: U4.22 (PA0); also elsewhere on the board
/OLED UI/BTN_RECORD: U4.28 (PA4); also elsewhere on the board
/OLED UI/BTN_RST: C13.1, J3.5, R5.2, U4.14 (NRST); also elsewhere on the board
/OLED UI/BTN_USER: U4.16 (PC1); also elsewhere on the board
/OLED UI/BTN_VOL_DOWN: U4.24 (PA2); also elsewhere on the board
/OLED UI/BTN_VOL_UP: U4.23 (PA1); also elsewhere on the board
/OLED UI/Col1: U4.34 (PB0); also elsewhere on the board
/OLED UI/Col2: U4.35 (PB1); also elsewhere on the board
/OLED UI/Col3: U4.36 (PB2); also elsewhere on the board
/OLED UI/OLED_BL: U4.91 (PB5); also elsewhere on the board
/OLED UI/OLED_CS: U4.92 (PB6); also elsewhere on the board
/OLED UI/OLED_DC: U4.93 (PB7); also elsewhere on the board
/OLED UI/OLED_MOSI: U4.31 (PA7); also elsewhere on the board
/OLED UI/OLED_RST: U4.30 (PA6); also elsewhere on the board
/OLED UI/OLED_SCK: U4.29 (PA5); also elsewhere on the board
/OLED UI/Row1: U4.89 (PB3); also elsewhere on the board
/OLED UI/Row2: U4.90 (PB4); also elsewhere on the board
/OLED UI/Row3: U4.15 (PC0); also elsewhere on the board
/Radio/GPO1: U4.53 (PB14); also elsewhere on the board
/Radio/GPO2/INT: U4.58 (PD11); also elsewhere on the board
/Radio/RADIO_I2S_BCLK: U4.46 (PB10); also elsewhere on the board
/Radio/RADIO_I2S_DATA: U4.54 (PB15); also elsewhere on the board
/Radio/RADIO_I2S_LRCLK: U4.51 (PB12); also elsewhere on the board
/Radio/RADIO_RST: U4.61 (PD14); also elsewhere on the board
/Radio/RADIO_SCL: U4.59 (PD12); also elsewhere on the board
/Radio/RADIO_SDA: U4.60 (PD13); also elsewhere on the board
/STM32 Core/PWR_I2C_SCL: U4.95 (PB8)
/STM32 Core/PWR_I2C_SDA: U4.96 (PB9)
/STM32 Core/SDMMC_CLK: U4.80 (PC12); also elsewhere on the board
/STM32 Core/SDMMC_CMD: U4.7 (PC13); also elsewhere on the board
/STM32 Core/SDMMC_D0: U4.65 (PC8); also elsewhere on the board
/STM32 Core/SDMMC_D1: U4.66 (PC9); also elsewhere on the board
/STM32 Core/SDMMC_D2: U4.78 (PC10); also elsewhere on the board
/STM32 Core/SDMMC_D3: U4.79 (PC11); also elsewhere on the board
/STM32 Core/SDMMC_DET: U4.64 (PC7); also elsewhere on the board
CLEANFILTERED3V3: C16.1, C22.1, C23.1, C24.1, FB1.1, U4.20 (VREF+), U4.21 (VDDA)
GAS_CS: U4.40 (PE10), U8.2 (CSB)
GND: C8.2, C10.2, C11.2, C13.2, C14.2, C15.2, C16.2, C17.2, C18.2, C19.2, C20.2, C21.2, C22.2, C23.2, C24.2, C25.2, C26.2, C27.2, C28.2, C29.2, C30.2, C31.2, C32.2, C33.2, J3.3, R6.2, U4.10 (VSS), U4.19 (VSSA), U4.26 (VSS), U4.49 (VSS), U4.74 (VSS), U4.99 (VSS), U5.2 (GND), U6.6 (GND), U6.7 (GND), U7.5 (GND), U7.6 (GND), U7.7 (GND), U7.8 (GND), U7.9 (GND), U7.10 (GND), U7.11 (GND), U7.12 (GND), U7.13 (GND), U8.1 (GND), U8.7 (GND); also elsewhere on the board
IMU_CS: U4.38 (PE8), U6.12 (CS)
IMU_INT1: U4.39 (PE9), U6.4 (INT1)
IMU_INT2: U4.17 (PC2_C), U6.9 (INT2)
LIGHT_INT: U4.18 (PC3_C), U5.4 (~INT)
unnamed: C18.1, U4.48 (VCAP)
unnamed: C21.1, U4.73 (VCAP)
OSC_IN: C8.1, U4.12 (PH0), Y1.1
OSC_OUT: C11.1, U4.13 (PH1), Y1.2
RTC_INT: R8.1, U4.69 (PA10), U7.3 (~INT/SQW)
RTC_RST: R7.2, U7.4 (~RST)
RTC_SCL: U4.67 (PA8), U7.16 (SCL)
RTC_SDA: U4.68 (PA9), U7.15 (SDA)
SENSORS_I2C_SCL: U4.81 (PD0), U5.5 (SCL)
SENSORS_I2C_SDA: U4.82 (PD1), U5.6 (SDA)
SENSORS_SPI1_MISO: U4.5 (PE6), U6.1 (SDO/SA0), U8.5 (SDO)
SENSORS_SPI1_MOSI: U4.37 (PE7), U6.14 (SDA), U8.3 (SDI)
SENSORS_SPI1_SCK: U4.43 (PE13), U6.13 (SCL), U8.4 (SCK)
SWCLK: J3.2, U4.76 (PA14)
SWDIO: J3.1, U4.72 (PA13)
USB_PROT_D+: U4.70 (PA11); also elsewhere on the board
USB_PROT_D-: U4.71 (PA12); also elsewhere on the board

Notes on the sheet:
SWD
temp pres humi gas
Light Sensor
imu

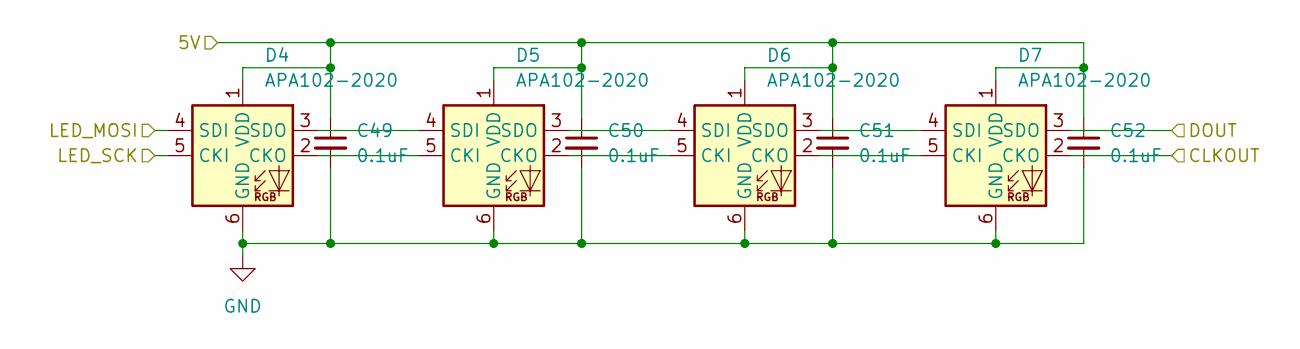
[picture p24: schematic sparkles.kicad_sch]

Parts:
C49, C50, C51, C52: 0.1uF; C_0603_1608Metric
D4, D5, D6, D7: APA102-2020; LED-APA102-2020

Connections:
+5V: C49.1, C50.1, C51.1, C52.1, D4.1 (VDD), D5.1 (VDD), D6.1 (VDD), D7.1 (VDD); also elsewhere on the board
/LED Spectrum/CLKOUT: D7.2 (CKO)
/LED Spectrum/DOUT: D7.3 (SDO)
/LED Spectrum/LED_MOSI: D4.4 (SDI); also elsewhere on the board
/LED Spectrum/LED_SCK: D4.5 (CKI); also elsewhere on the board
GND: C49.2, C50.2, C51.2, C52.2, D4.6 (GND), D5.6 (GND), D6.6 (GND), D7.6 (GND); also elsewhere on the board
unnamed: D4.2 (CKO), D5.5 (CKI)
unnamed: D4.3 (SDO), D5.4 (SDI)
unnamed: D5.2 (CKO), D6.5 (CKI)
unnamed: D5.3 (SDO), D6.4 (SDI)
unnamed: D6.2 (CKO), D7.5 (CKI)
unnamed: D6.3 (SDO), D7.4 (SDI)

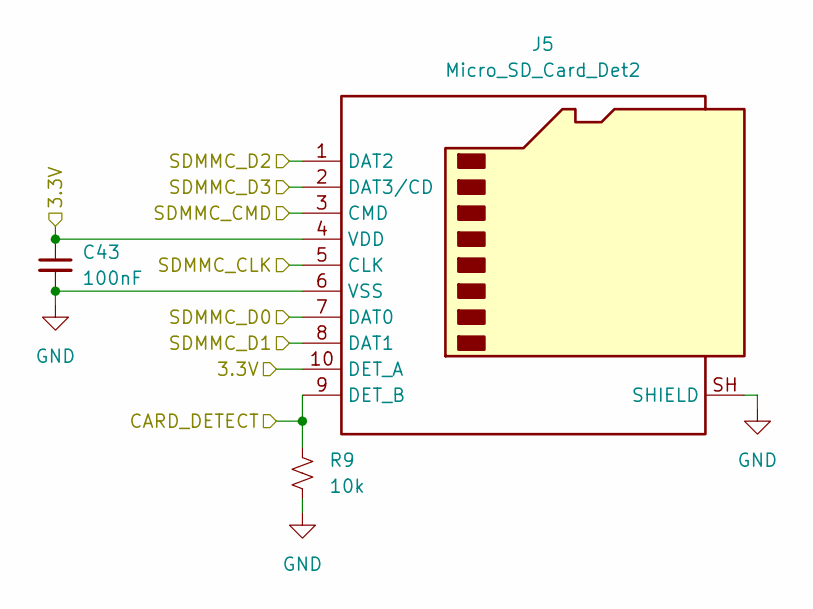
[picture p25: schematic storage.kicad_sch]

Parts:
C43: 100nF; C_0603_1608Metric
J5: Micro_SD_Card_Det2; microSD_HC_Hirose_DM3D-SF
R9: 10k; R_0603_1608Metric

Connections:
+3.3V: C43.1, J5.4 (VDD), J5.10 (DET_A); also elsewhere on the board
/STM32 Core/SDMMC_CLK: J5.5 (CLK); also elsewhere on the board
/STM32 Core/SDMMC_CMD: J5.3 (CMD); also elsewhere on the board
/STM32 Core/SDMMC_D0: J5.7 (DAT0); also elsewhere on the board
/STM32 Core/SDMMC_D1: J5.8 (DAT1); also elsewhere on the board
/STM32 Core/SDMMC_D2: J5.1 (DAT2); also elsewhere on the board
/STM32 Core/SDMMC_D3: J5.2 (DAT3/CD); also elsewhere on the board
/STM32 Core/SDMMC_DET: J5.9 (DET_B), R9.1; also elsewhere on the board
GND: C43.2, J5.6 (VSS), J5.SH (SHIELD), R9.2; also elsewhere on the board

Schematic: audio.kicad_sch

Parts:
C34, C35, C41: 100nF; C_0603_1608Metric
C36, C37: 15uF; C_0603_1608Metric
C38, C39, C40: 2.2uF; C_0603_1608Metric
C42: 4.7uF; C_0603_1608Metric
J4: AudioJack3_Ground_SwitchTR; Jack_3.5mm_PJ31060-I_Horizontal
TP3: TestPoint; TestPoint_Pad_D1.5mm
U9: CS43131-CNZR; TQFN-40-1EP_5x5mm_P0.4mm_EP3.5x3.5mm; MPN CS43131-CNZR; LCSC Part C965907

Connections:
+3.3VA: C41.1, C42.1, U9.26 (VP); also elsewhere on the board
/Audio/1.8v: C34.1, C35.1, C36.2, C40.1, U9.4 (VD), U9.7 (VA), U9.25 (VCP), U9.31 (VL); also elsewhere on the board
/Audio/I2S_BCLK: U9.34 (SCLK1); also elsewhere on the board
/Audio/I2S_LRCLK: U9.38 (LRCK1); also elsewhere on the board
/Audio/I2S_MCLK: U9.37 (XTI/MCLK); also elsewhere on the board
/Audio/I2S_SDOUT: U9.2 (SDIN1); also elsewhere on the board
/Audio/INT: U9.27 (~INT); also elsewhere on the board
/Audio/RESET: U9.28 (~RESET); also elsewhere on the board
/Audio/SCL: U9.1 (SCL); also elsewhere on the board
/Audio/SDA: U9.39 (SDA); also elsewhere on the board
/Audio/VCP_FILT/FLYC_VCP: U9.23 (FLYC_VCP); also elsewhere on the board
/Audio/VCP_FILT/FLYN_VCP: U9.20 (FLYN_VCP); also elsewhere on the board
/Audio/VCP_FILT/FLYP_VCP: U9.24 (FLYP_VCP); also elsewhere on the board
/Audio/VCP_FILT/GNDCP: U9.19 (GNDCP); also elsewhere on the board
/Audio/VCP_FILT/VCP_FILT+: U9.21 (VCP_FILT+); also elsewhere on the board
/Audio/VCP_FILT/VCP_FILT-: U9.18 (VCP_FILT–); also elsewhere on the board
GND: C34.2, C35.2, C39.2, C40.2, C41.2, C42.2, J4.1, J4.2, U9.8 (GNDA), U9.13 (HPREFA), U9.17 (HPREFB), U9.30 (ADR), U9.35 (GNDD), U9.36 (XTO), U9.41 (EP); also elsewhere on the board
unnamed: C37.1, C39.1, U9.9 (-VA)
unnamed: TP3.1 (1_1), U9.33 (CLKOUT)
unnamed: C36.1, U9.5 (FILT+)
unnamed: C37.2, U9.6 (FILT–)
unnamed: C38.2, U9.11 (FLYN_VA)
unnamed: C38.1, U9.10 (FLYP_VA)
unnamed: J4.4, U9.14 (HPOUTA)
unnamed: J4.3, U9.16 (HPOUTB)
unnamed: J4.6, U9.22 (HP_DETECT)

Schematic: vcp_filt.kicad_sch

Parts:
C54, C55, C56, C57, C58: 2.2uF; C_0603_1608Metric

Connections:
/Audio/1.8v: C58.1; also elsewhere on the board
/Audio/VCP_FILT/FLYC_VCP: C55.2, C56.1; also elsewhere on the board
/Audio/VCP_FILT/FLYN_VCP: C56.2; also elsewhere on the board
/Audio/VCP_FILT/FLYP_VCP: C55.1; also elsewhere on the board
/Audio/VCP_FILT/GNDCP: C54.2, C57.2, C58.2; also elsewhere on the board
/Audio/VCP_FILT/VCP_FILT+: C57.1; also elsewhere on the board
/Audio/VCP_FILT/VCP_FILT-: C54.1; also elsewhere on the board

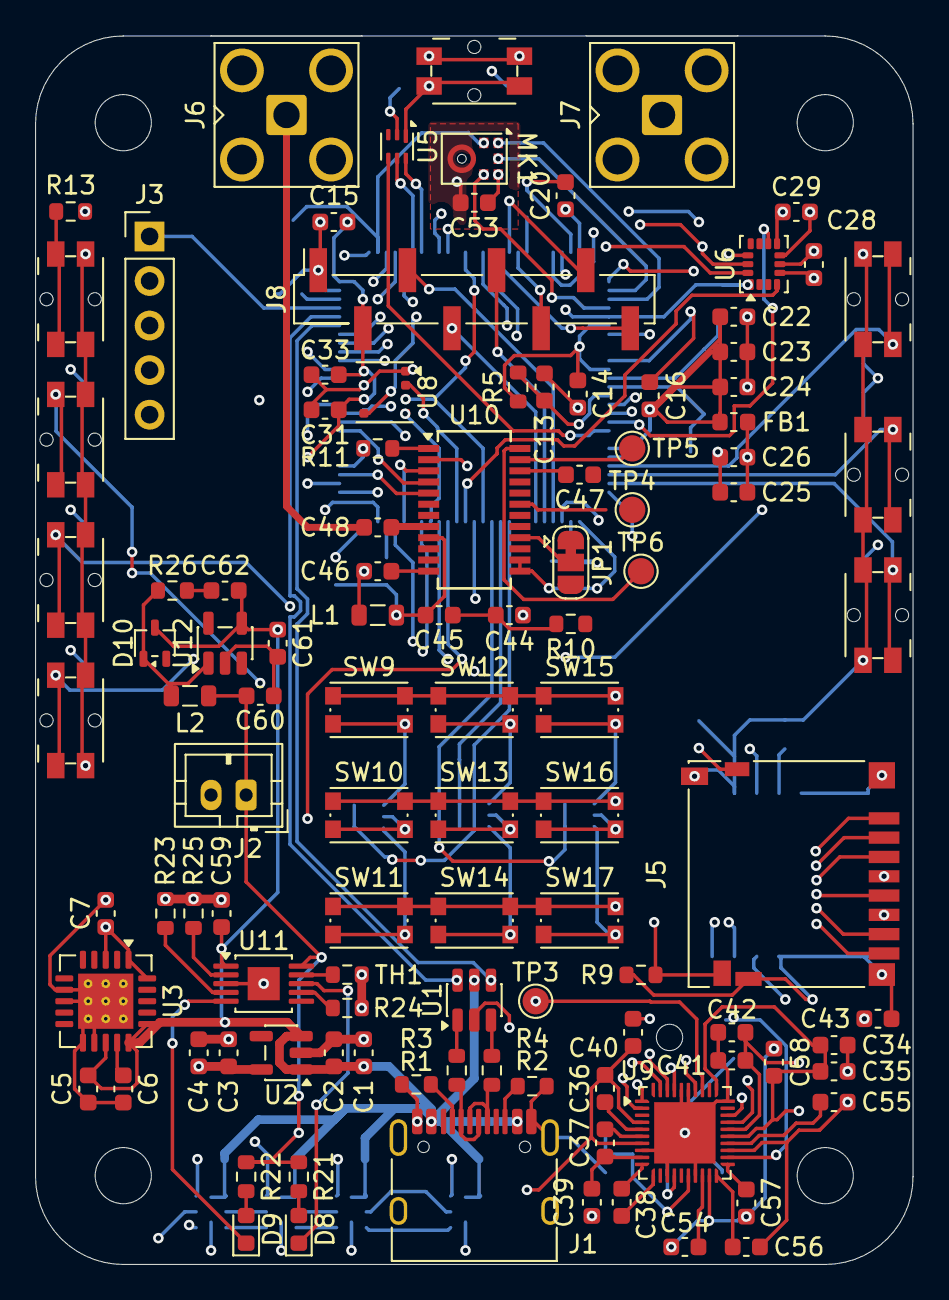
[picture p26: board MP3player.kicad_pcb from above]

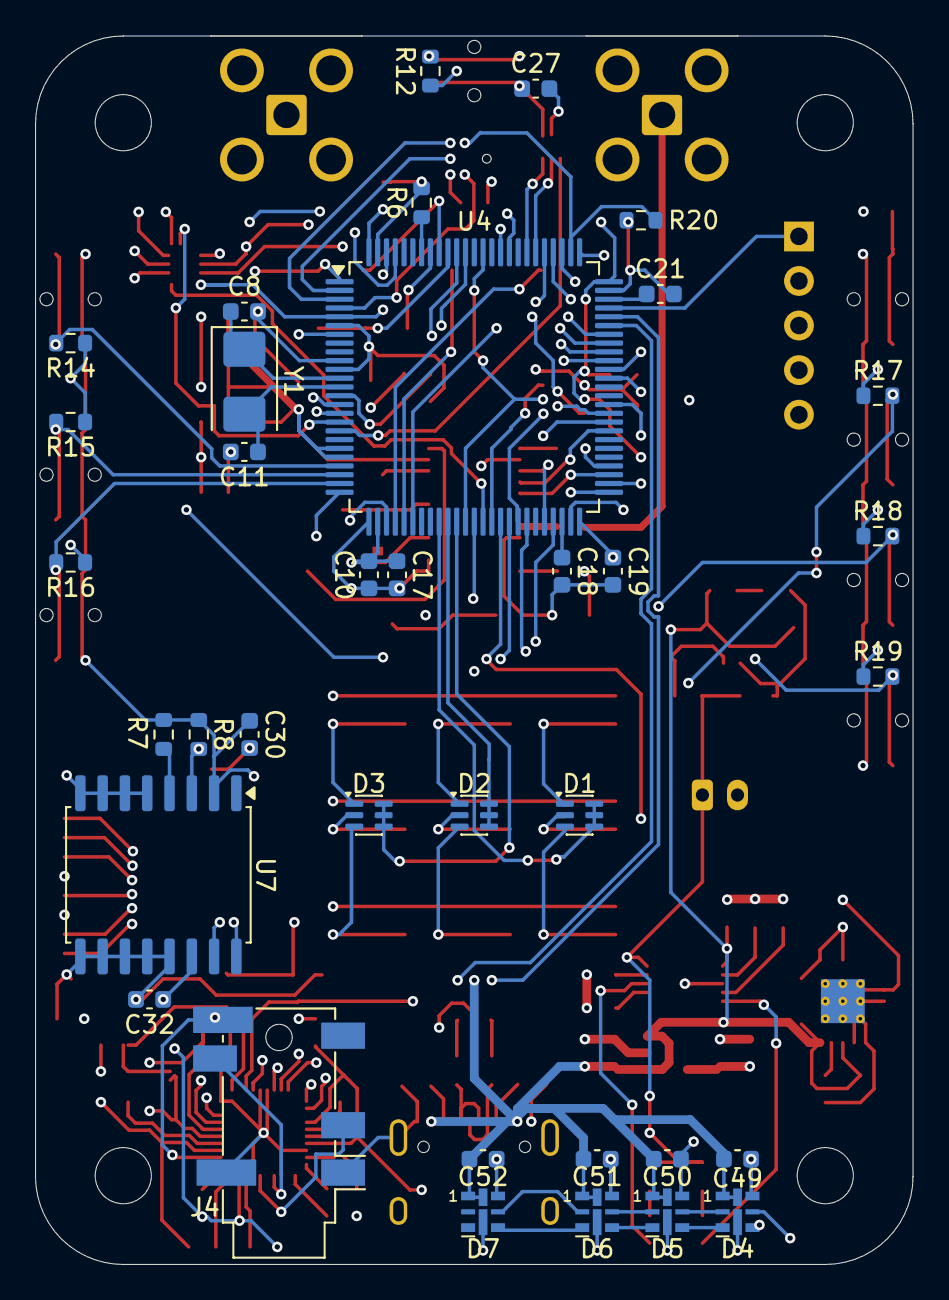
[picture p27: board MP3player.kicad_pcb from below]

Board: 6 copper layers, 50.0 x 70.0 mm, 148 parts (36 on the bottom side), 136 nets.

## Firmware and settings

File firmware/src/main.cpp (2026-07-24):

#include "stm32h7xx_hal.h"
#include "pins.h"
#include "config.h"

extern "C" {
extern UART_HandleTypeDef huart_pmm;
extern I2C_HandleTypeDef hi2c_sensors;
extern I2C_HandleTypeDef hi2c_audio;
extern I2C_HandleTypeDef hi2c_pwr;
extern I2C_HandleTypeDef hi2c_rtc;
extern I2C_HandleTypeDef hi2c_radio;
extern SPI_HandleTypeDef hspi_oled;
extern SPI_HandleTypeDef hspi_sensors;
extern SD_HandleTypeDef hsd1;

void SystemClock_Config(void);
void GPIO_Init(void);
void Error_Handler(void);
}

static void MX_I2C_Init(I2C_HandleTypeDef *hi2c, I2C_TypeDef *instance, uint32_t timing_val)
{
    hi2c->Instance = instance;
    hi2c->Init.Timing = timing_val;
    hi2c->Init.OwnAddress1 = 0;
    hi2c->Init.AddressingMode = I2C_ADDRESSINGMODE_7BIT;
    hi2c->Init.DualAddressMode = I2C_DUALADDRESS_DISABLE;
    hi2c->Init.GeneralCallMode = I2C_GENERALCALL_DISABLE;
    hi2c->Init.NoStretchMode = I2C_NOSTRETCH_DISABLE;
    if (HAL_I2C_Init(hi2c) != HAL_OK) {
        Error_Handler();
    }
}

static void MX_SPI_Init(SPI_HandleTypeDef *hspi, SPI_TypeDef *instance)
{
    hspi->Instance = instance;
    hspi->Init.Mode = SPI_MODE_MASTER;
    hspi->Init.Direction = SPI_DIRECTION_2LINES;
    hspi->Init.DataSize = SPI_DATASIZE_8BIT;
    hspi->Init.CLKPolarity = SPI_POLARITY_HIGH;
    hspi->Init.CLKPhase = SPI_PHASE_2EDGE;
    hspi->Init.NSS = SPI_NSS_SOFT;
    hspi->Init.BaudRatePrescaler = SPI_BAUDRATEPRESCALER_4;
    hspi->Init.FirstBit = SPI_FIRSTBIT_MSB;
    hspi->Init.TIMode = SPI_TIMODE_DISABLE;
    hspi->Init.CRCCalculation = SPI_CRCCALCULATION_DISABLE;
    hspi->Init.CRCPolynomial = 0x0;
    hspi->Init.CRCLength = SPI_CRC_LENGTH_DATASIZE;
    hspi->Init.NSSPMode = SPI_NSS_PULSE_DISABLE;
    if (HAL_SPI_Init(hspi) != HAL_OK) {
        Error_Handler();
    }
}

static void MX_UART_Init(UART_HandleTypeDef *huart, USART_TypeDef *instance)
{
    huart->Instance = instance;
    huart->Init.BaudRate = cfg::UART_PMM_BAUD;
    huart->Init.WordLength = UART_WORDLENGTH_8B;
    huart->Init.StopBits = UART_STOPBITS_1;
    huart->Init.Parity = UART_PARITY_NONE;
    huart->Init.Mode = UART_MODE_TX_RX;
    huart->Init.HwFlowCtl = UART_HWCONTROL_NONE;
    huart->Init.OverSampling = UART_OVERSAMPLING_16;
    huart->Init.OneBitSampling = UART_ONE_BIT_SAMPLE_DISABLE;
    huart->Init.ClockPrescaler = UART_PRESCALER_DIV1;
    if (HAL_UART_Init(huart) != HAL_OK) {
        Error_Handler();
    }
}

extern "C" void SystemClock_Config(void)
{
    RCC_OscInitTypeDef RCC_OscInitStruct = {};
    RCC_ClkInitTypeDef RCC_ClkInitStruct = {};
    RCC_PeriphCLKInitTypeDef PeriphClkInit = {};

    HAL_PWREx_ConfigSupply(PWR_LDO_SUPPLY);
    __HAL_PWR_VOLTAGESCALING_CONFIG(PWR_REGULATOR_VOLTAGE_SCALE0);
    while (!__HAL_PWR_GET_FLAG(PWR_FLAG_VOSRDY)) {}

    RCC_OscInitStruct.OscillatorType = RCC_OSCILLATORTYPE_HSE | RCC_OSCILLATORTYPE_LSE;
    RCC_OscInitStruct.HSEState = RCC_HSE_ON;
    RCC_OscInitStruct.LSEState = RCC_LSE_ON;
    RCC_OscInitStruct.PLL.PLLState = RCC_PLL_ON;
    RCC_OscInitStruct.PLL.PLLSource = RCC_PLLSOURCE_HSE;
    RCC_OscInitStruct.PLL.PLLM = 4;
    RCC_OscInitStruct.PLL.PLLN = 240;
    RCC_OscInitStruct.PLL.PLLP = 1;
    RCC_OscInitStruct.PLL.PLLQ = 10;
    RCC_OscInitStruct.PLL.PLLR = 2;
    RCC_OscInitStruct.PLL.PLLRGE = RCC_PLL1VCIRANGE_2;
    RCC_OscInitStruct.PLL.PLLVCOSEL = RCC_PLL1VCOWIDE;
    RCC_OscInitStruct.PLL.PLLFRACN = 0;
    if (HAL_RCC_OscConfig(&RCC_OscInitStruct) != HAL_OK) {
        Error_Handler();
    }

    RCC_ClkInitStruct.ClockType = RCC_CLOCKTYPE_HCLK | RCC_CLOCKTYPE_SYSCLK
                                | RCC_CLOCKTYPE_PCLK1 | RCC_CLOCKTYPE_PCLK2
                                | RCC_CLOCKTYPE_D1PCLK1 | RCC_CLOCKTYPE_D3PCLK1;
    RCC_ClkInitStruct.SYSCLKSource = RCC_SYSCLKSOURCE_PLLCLK;
    RCC_ClkInitStruct.SYSCLKDivider = RCC_SYSCLK_DIV1;
    RCC_ClkInitStruct.AHBCLKDivider = RCC_HCLK_DIV2;
    RCC_ClkInitStruct.APB1CLKDivider = RCC_APB1_DIV2;
    RCC_ClkInitStruct.APB2CLKDivider = RCC_APB2_DIV2;
    RCC_ClkInitStruct.APB3CLKDivider = RCC_APB3_DIV2;
    RCC_ClkInitStruct.APB4CLKDivider = RCC_APB4_DIV2;
    if (HAL_RCC_ClockConfig(&RCC_ClkInitStruct, FLASH_LATENCY_4) != HAL_OK) {
        Error_Handler();
    }

    PeriphClkInit.PeriphClockSelection = RCC_PERIPHCLK_USART3 | RCC_PERIPHCLK_I2C1
                                       | RCC_PERIPHCLK_I2C2 | RCC_PERIPHCLK_I2C3
                                       | RCC_PERIPHCLK_SAI1 | RCC_PERIPHCLK_SAI23
                                       | RCC_PERIPHCLK_SDMMC | RCC_PERIPHCLK_SPI123
                                       | RCC_PERIPHCLK_SPI45 | RCC_PERIPHCLK_USART1;

    PeriphClkInit.Sai1ClockSelection = RCC_SAI1CLKSOURCE_PLL2;
    PeriphClkInit.Sai23ClockSelection = RCC_SAI2CLKSOURCE_PLL2;
    PeriphClkInit.Usart16ClockSelection = RCC_USART16CLKSOURCE_D2PCLK2;
    PeriphClkInit.I2c123ClockSelection = RCC_I2C123CLKSOURCE_D2PCLK1;
    PeriphClkInit.I2c4ClockSelection = RCC_I2C4CLKSOURCE_D3PCLK1;
    PeriphClkInit.SdmmcClockSelection = RCC_SDMMCCLKSOURCE_PLL;
    PeriphClkInit.Spi123ClockSelection = RCC_SPI123CLKSOURCE_PLL2;
    PeriphClkInit.Spi45ClockSelection = RCC_SPI45CLKSOURCE_D2PCLK1;

    PeriphClkInit.PLL2.PLL2M = 4;
    PeriphClkInit.PLL2.PLL2N = 198;
    PeriphClkInit.PLL2.PLL2P = 5;
    PeriphClkInit.PLL2.PLL2Q = 2;
    PeriphClkInit.PLL2.PLL2R = 2;
    PeriphClkInit.PLL2.PLL2RGE = RCC_PLL2VCIRANGE_2;
    PeriphClkInit.PLL2.PLL2VCOSEL = RCC_PLL2VCOWIDE;
    PeriphClkInit.PLL2.PLL2FRACN = 0;

    if (HAL_RCCEx_PeriphCLKConfig(&PeriphClkInit) != HAL_OK) {
        Error_Handler();
    }
}

extern "C" void GPIO_Init(void)
{
    GPIO_InitTypeDef GPIO_InitStruct = {};

    __HAL_RCC_GPIOA_CLK_ENABLE();
    __HAL_RCC_GPIOB_CLK_ENABLE();
    __HAL_RCC_GPIOC_CLK_ENABLE();
    __HAL_RCC_GPIOD_CLK_ENABLE();
    __HAL_RCC_GPIOE_CLK_ENABLE();

    GPIO_InitStruct.Pin = BTN_POWER_Pin | BTN_VOL_UP_Pin | BTN_VOL_DOWN_Pin
                        | BTN_LOCK_Pin | BTN_RECORD_Pin | MIC_CHANNEL_Pin;
    GPIO_InitStruct.Mode = GPIO_MODE_INPUT;
    GPIO_InitStruct.Pull = GPIO_PULLUP;
    HAL_GPIO_Init(GPIOA, &GPIO_InitStruct);

    GPIO_InitStruct.Pin = BTN_MATRIX_COL1_Pin | BTN_MATRIX_COL2_Pin | BTN_MATRIX_COL3_Pin
                        | BTN_MATRIX_ROW1_Pin | BTN_MATRIX_ROW2_Pin;
    HAL_GPIO_Init(GPIOB, &GPIO_InitStruct);

    GPIO_InitStruct.Pin = BTN_BOOT0_Pin | BTN_USER_Pin | BTN_MATRIX_ROW3_Pin
                        | IMU_INT2_Pin | LIGHT_INT_Pin;
    HAL_GPIO_Init(GPIOC, &GPIO_InitStruct);

    GPIO_InitStruct.Pin = OLED_CS_Pin;
    GPIO_InitStruct.Mode = GPIO_MODE_OUTPUT_PP;
    GPIO_InitStruct.Pull = GPIO_NOPULL;
    GPIO_InitStruct.Speed = GPIO_SPEED_FREQ_HIGH;
    HAL_GPIO_Init(OLED_CS_Port, &GPIO_InitStruct);
    HAL_GPIO_WritePin(OLED_CS_Port, OLED_CS_Pin, GPIO_PIN_SET);

    GPIO_InitStruct.Pin = OLED_DC_Pin;
    HAL_GPIO_Init(OLED_DC_Port, &GPIO_InitStruct);

    GPIO_InitStruct.Pin = OLED_RST_Pin;
    HAL_GPIO_Init(OLED_RST_Port, &GPIO_InitStruct);
    HAL_GPIO_WritePin(OLED_RST_Port, OLED_RST_Pin, GPIO_PIN_SET);

    GPIO_InitStruct.Pin = OLED_BL_Pin;
    HAL_GPIO_Init(OLED_BL_Port, &GPIO_InitStruct);

    GPIO_InitStruct.Pin = IMU_CS_Pin;
    HAL_GPIO_Init(IMU_CS_Port, &GPIO_InitStruct);
    HAL_GPIO_WritePin(IMU_CS_Port, IMU_CS_Pin, GPIO_PIN_SET);

    GPIO_InitStruct.Pin = GAS_CS_Pin;
    HAL_GPIO_Init(GAS_CS_Port, &GPIO_InitStruct);
    HAL_GPIO_WritePin(GAS_CS_Port, GAS_CS_Pin, GPIO_PIN_SET);

    GPIO_InitStruct.Pin = AUDIO_RESET_Pin;
    HAL_GPIO_Init(AUDIO_RESET_Port, &GPIO_InitStruct);
    HAL_GPIO_WritePin(AUDIO_RESET_Port, AUDIO_RESET_Pin, GPIO_PIN_SET);

    GPIO_InitStruct.Pin = PMM_SHDN_Pin | PMM_FORCE_Pin;
    HAL_GPIO_Init(GPIOD, &GPIO_InitStruct);

    GPIO_InitStruct.Pin = RADIO_RST_Pin;
    HAL_GPIO_Init(RADIO_RST_Port, &GPIO_InitStruct);
    HAL_GPIO_WritePin(RADIO_RST_Port, RADIO_RST_Pin, GPIO_PIN_SET);

    GPIO_InitStruct.Pin = SDMMC_DET_Pin;
    GPIO_InitStruct.Mode = GPIO_MODE_INPUT;
    GPIO_InitStruct.Pull = GPIO_PULLUP;
    HAL_GPIO_Init(SDMMC_DET_Port, &GPIO_InitStruct);
}

int main(void)
{
    HAL_Init();
    SystemClock_Config();
    GPIO_Init();

    MX_I2C_Init(&hi2c_sensors, I2C1, 0x10C0ECFF);
    MX_I2C_Init(&hi2c_audio, I2C4, 0x10C0ECFF);
    MX_I2C_Init(&hi2c_pwr, I2C2, 0x307075B1);
    MX_I2C_Init(&hi2c_rtc, I2C3, 0x10C0ECFF);

    MX_SPI_Init(&hspi_oled, SPI4);
    MX_SPI_Init(&hspi_sensors, SPI1);

    MX_UART_Init(&huart_pmm, USART3);

    while (true) {
        HAL_Delay(100);
    }
}

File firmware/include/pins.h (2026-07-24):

#pragma once

#include "stm32h7xx_hal.h"

// ─── Buttons (direct GPIO, active low) ─────────────────────────────
#define BTN_POWER_Pin       GPIO_PIN_0
#define BTN_POWER_Port      GPIOA
#define BTN_VOL_UP_Pin      GPIO_PIN_1
#define BTN_VOL_UP_Port     GPIOA
#define BTN_VOL_DOWN_Pin    GPIO_PIN_2
#define BTN_VOL_DOWN_Port   GPIOA
#define BTN_LOCK_Pin        GPIO_PIN_3
#define BTN_LOCK_Port       GPIOA
#define BTN_RECORD_Pin      GPIO_PIN_4
#define BTN_RECORD_Port     GPIOA
#define BTN_USER_Pin        GPIO_PIN_1
#define BTN_USER_Port       GPIOC
#define BTN_BOOT0_Pin       GPIO_PIN_0
#define BTN_BOOT0_Port      GPIOC

// ─── Button Matrix ─────────────────────────────────────────────────
#define BTN_MATRIX_ROW1_Pin GPIO_PIN_3
#define BTN_MATRIX_ROW1_Port GPIOB
#define BTN_MATRIX_ROW2_Pin GPIO_PIN_4
#define BTN_MATRIX_ROW2_Port GPIOB
#define BTN_MATRIX_ROW3_Pin GPIO_PIN_0
#define BTN_MATRIX_ROW3_Port GPIOC
#define BTN_MATRIX_COL1_Pin GPIO_PIN_0
#define BTN_MATRIX_COL1_Port GPIOB
#define BTN_MATRIX_COL2_Pin GPIO_PIN_1
#define BTN_MATRIX_COL2_Port GPIOB
#define BTN_MATRIX_COL3_Pin GPIO_PIN_2
#define BTN_MATRIX_COL3_Port GPIOB

// ─── OLED Display (SPI) ───────────────────────────────────────────
#define OLED_SCK_Pin        GPIO_PIN_5
#define OLED_SCK_Port       GPIOA
#define OLED_MOSI_Pin       GPIO_PIN_7
#define OLED_MOSI_Port      GPIOA
#define OLED_CS_Pin         GPIO_PIN_6
#define OLED_CS_Port        GPIOB
#define OLED_DC_Pin         GPIO_PIN_7
#define OLED_DC_Port        GPIOB
#define OLED_RST_Pin        GPIO_PIN_6
#define OLED_RST_Port       GPIOA
#define OLED_BL_Pin         GPIO_PIN_5
#define OLED_BL_Port        GPIOB

// ─── I2S Audio (CS43131 DAC) ───────────────────────────────────────
#define I2S_MCLK_Pin        GPIO_PIN_1
#define I2S_MCLK_Port       GPIOE
#define I2S_SDOUT_Pin       GPIO_PIN_14
#define I2S_SDOUT_Port      GPIOE
#define I2S_BCLK_Pin        GPIO_PIN_12
#define I2S_BCLK_Port       GPIOE
#define I2S_LRCLK_Pin       GPIO_PIN_11
#define I2S_LRCLK_Port      GPIOE
#define AUDIO_RESET_Pin     GPIO_PIN_4
#define AUDIO_RESET_Port    GPIOD
#define AUDIO_INT_Pin       GPIO_PIN_3
#define AUDIO_INT_Port      GPIOD

// ─── I2C: Audio DAC control ────────────────────────────────────────
#define AUDIO_SCL_Pin       GPIO_PIN_1
#define AUDIO_SCL_Port      GPIOE
#define AUDIO_SDA_Pin       GPIO_PIN_0
#define AUDIO_SDA_Port      GPIOE

// ─── I2C: Sensors (LSM6DSL, ISL29035, BME680) ────────────────────
#define SENSORS_I2C_SCL_Pin  GPIO_PIN_0
#define SENSORS_I2C_SCL_Port GPIOD
#define SENSORS_I2C_SDA_Pin  GPIO_PIN_1
#define SENSORS_I2C_SDA_Port GPIOD

// ─── SPI: Sensors (LSM6DSL, BME680) ───────────────────────────────
#define SENSORS_SPI_SCK_Pin  GPIO_PIN_13
#define SENSORS_SPI_SCK_Port GPIOE
#define SENSORS_SPI_MISO_Pin GPIO_PIN_5
#define SENSORS_SPI_MISO_Port GPIOE
#define SENSORS_SPI_MOSI_Pin GPIO_PIN_6
#define SENSORS_SPI_MOSI_Port GPIOE
#define IMU_CS_Pin           GPIO_PIN_8
#define IMU_CS_Port          GPIOE
#define GAS_CS_Pin           GPIO_PIN_10
#define GAS_CS_Port          GPIOE
#define IMU_INT1_Pin         GPIO_PIN_9
#define IMU_INT1_Port        GPIOE
#define IMU_INT2_Pin         GPIO_PIN_2
#define IMU_INT2_Port        GPIOC
#define LIGHT_INT_Pin        GPIO_PIN_3
#define LIGHT_INT_Port       GPIOC

// ─── I2S: Microphone (ICS-43434) ──────────────────────────────────
#define MIC_DATA_Pin        GPIO_PIN_2
#define MIC_DATA_Port       GPIOE
#define MIC_LRCLK_Pin       GPIO_PIN_3
#define MIC_LRCLK_Port      GPIOE
#define MIC_BCLK_Pin        GPIO_PIN_4
#define MIC_BCLK_Port       GPIOE
#define MIC_CHANNEL_Pin     GPIO_PIN_15
#define MIC_CHANNEL_Port    GPIOA

// ─── I2S: Radio (Si4735) ──────────────────────────────────────────
#define RADIO_I2S_BCLK_Pin  GPIO_PIN_10
#define RADIO_I2S_BCLK_Port GPIOB
#define RADIO_I2S_LRCLK_Pin GPIO_PIN_12
#define RADIO_I2S_LRCLK_Port GPIOB
#define RADIO_I2S_DATA_Pin  GPIO_PIN_15
#define RADIO_I2S_DATA_Port GPIOB
#define RADIO_SCL_Pin       GPIO_PIN_12
#define RADIO_SCL_Port      GPIOD
#define RADIO_SDA_Pin       GPIO_PIN_13
#define RADIO_SDA_Port      GPIOD
#define RADIO_RST_Pin       GPIO_PIN_14
#define RADIO_RST_Port      GPIOD
#define RADIO_IRQ_Pin       GPIO_PIN_11
#define RADIO_IRQ_Port      GPIOD
#define RADIO_GP1_Pin       GPIO_PIN_14
#define RADIO_GP1_Port      GPIOB

// ─── LED Strip (APA102) ───────────────────────────────────────────
#define LED_SCK_Pin         GPIO_PIN_11
#define LED_SCK_Port        GPIOB
#define LED_MOSI_Pin        GPIO_PIN_13
#define LED_MOSI_Port       GPIOB
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

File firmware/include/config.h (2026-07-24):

#pragma once

#include <cstdint>

namespace cfg {
    // System
    constexpr uint32_t SYSCLK_FREQ_HZ = 480000000U;
    constexpr uint32_t APB1_FREQ_HZ    = 120000000U;
    constexpr uint32_t APB2_FREQ_HZ    = 120000000U;

    // I2C bus speeds
    constexpr uint32_t I2C_SENSORS_FREQ  = 400000U;
    constexpr uint32_t I2C_AUDIO_FREQ    = 400000U;
    constexpr uint32_t I2C_RADIO_FREQ    = 400000U;
    constexpr uint32_t I2C_RTC_FREQ      = 400000U;
    constexpr uint32_t I2C_PWR_FREQ      = 100000U;

    // SPI frequencies
    constexpr uint32_t SPI_OLED_FREQ     = 40000000U;
    constexpr uint32_t SPI_SENSORS_FREQ  = 10000000U;

    // UART
    constexpr uint32_t UART_PMM_BAUD    = 115200U;

    // Audio
    constexpr uint32_t AUDIO_SAMPLE_RATE = 44100U;
    constexpr uint32_t I2S_MCLK_FREQ     = 11289600U; // 256 * 44100

    // LED strip
    constexpr uint16_t NUM_LEDS_SPARKLES  = 35;
    constexpr uint16_t NUM_LEDS_SPECTRUM  = 35;
    constexpr uint16_t NUM_LEDS_TOTAL     = NUM_LEDS_SPARKLES + NUM_LEDS_SPECTRUM;

    // Button scan
    constexpr uint32_t BTN_DEBOUNCE_MS    = 30;
    constexpr uint32_t BTN_SCAN_INTERVAL_MS = 5;

    // PMM I2C address (STM32-based PMM module)
    constexpr uint8_t PMM_I2C_ADDR = 0x55;
}

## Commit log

2026-07-22 add PMM instead of poewr stage
    [power.kicad_sch]
2026-07-24 almost done schematic
    [MP3player.kicad_pcb, MP3player.kicad_sch, audio.kicad_sch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]
2026-07-24 changes to audio sheet
    [audio.kicad_sch]
2026-07-24 add sensors
    [stm32core.kicad_sch]
2026-07-25 almost done!
    [MP3player.kicad_pcb, MP3player.kicad_sch, audio.kicad_sch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]
2026-07-25 add images
    [MP3player.kicad_pcb]
2026-07-26 general changes
    [MP3player.kicad_pcb, MP3player.kicad_sch, audio.kicad_sch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]
2026-07-29 fininshed pcb and fixed drc errors
    [MP3player.kicad_pcb, MP3player.kicad_sch, audio.kicad_sch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]
2026-07-29 fix images
    [MP3player.kicad_pcb]
2026-07-29 add bom and production files
    [bom.csv, designators.csv, positions.csv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]
2026-07-29 add time and fix bom
    [BOM.csv, bom.csv]
2026-07-29 update bom
    [BOM.csv]
2026-07-30 add cad models
2026-07-30 removed unncecessary pcb files
    [untitled.kicad_sch]
2026-08-01 polish readme
    [MP3player.blend]
2026-08-18 add gerbers
